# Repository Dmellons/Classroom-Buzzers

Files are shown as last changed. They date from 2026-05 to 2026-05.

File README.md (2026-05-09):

# ESP32 Quiz Buzzer System

A professional quiz buzzer system built with ESP32-C6 microcontrollers, featuring wireless button communication via ESP-NOW, web-based configuration, and real-time OLED display feedback.




## 🎯 Features

- **Up to 9 Teams**: Support for 1-9 wireless buzzer buttons
- **ESP-NOW Communication**: Ultra-low latency (<10ms) wireless protocol
- **Web Configuration Interface**: Easy setup via WiFi hotspot
- **OLED Display**: Real-time game status, team names, and winner display
- **SD Card Logging**: Permanent record of all buzzer events with timestamps
- **Auto-Load Configuration**: Team names and settings automatically restored on power-up
- **Built-in LED Feedback**: Arcade buttons with integrated illumination
- **Battery Powered Buttons**: Rechargeable 18650 Li-ion batteries with TP4056 charging
- **Persistent Configuration**: Team names and settings saved to SD card

## 📸 Demo

*[Add photos of your completed system here]*

## 🛠️ Hardware Requirements

### Base Station (1x)
- ESP32-C6-DevKitC-1 development board
- 128x64 OLED Display (I2C, SSD1306)
- MicroSD Card Reader Module (SPI)
- MicroSD Card (formatted FAT32)
- USB cable for power
- Jumper wires

### Button Units (1-9x, one per team)
- ESP32-C6-DevKitC-1 development board
- 60mm LED Arcade Button
- 18650 Li-ion Battery (3.7V, protected recommended)
- TP4056 Battery Charging Module
- MT3608 DC-DC Boost Converter (x2 per button)
- 10kΩ Resistor
- 1kΩ Resistor (for transistor base)
- 2N2222 or similar NPN transistor (for LED control)
- Toggle Switch (power switch)
- 18650 Battery Holder
- Jumper wires

### Optional
- WS2812B LED Strip (for visual effects on base station)
- Logic Level Converter (3.3V to 5V, if using LED strip)
- External 5V power supply (for LED strip)

## 📁 Repository Structure

```
Classroom Buzzers/
├── base-station/              # Base station code
│   ├── base-station.ino       # Main base station firmware
│   ├── base-secret.h          # WiFi credentials (create from template)
│   └── README.md              # Base station setup guide
├── button/                    # Button unit code
│   ├── button.ino             # Main button firmware
│   ├── button-secret.h        # Base station MAC (create from template)
│   └── README.md              # Button unit setup guide
├── debug/                     # Debug utilities
│   └── debug.ino              # Hardware diagnostic tool
├── tests/                     # Test utilities
│   └── blink-test/
│       └── blink-test.ino     # Basic LED blink test
├── components-list.md         # Complete hardware BOM and wiring
├── button-wiring-guide.md     # Detailed button wiring guide
├── breadboard-button-guide.md # Simplified breadboard setup
├── speaker-wiring-guide.md    # Audio system wiring
├── CLAUDE.md                  # Development guide for AI assistance
├── LICENSE                    # MIT License
└── README.md                  # This file
```

## Secret Configuration Files

These files contain sensitive information (WiFi credentials and MAC addresses) and should not be committed to version control.

You will need to create two secret files - one for the base station and one for each button unit:

### base-station/base-secret.h
```cpp
#define WIFI_SSID "QuizBuzzer-Setup"
#define WIFI_PASSWORD "buzzer123"
```

### button/button-secret.h
```cpp
#define BASE_STATION_MAC {0x00, 0x00, 0x00, 0x00, 0x00, 0x00}
```

## 🚀 Quick Start

### 1. Flash the Base Station
1. Open `base-station/base-station.ino` in Arduino IDE
2. Select **Board: "ESP32C6 Dev Module"**
3. Install required libraries (see base-station/README.md)
4. Upload the code
5. Note the MAC address from Serial Monitor

### 2. Flash the Buttons
1. Open `button/button.ino` in Arduino IDE
2. Update `baseStationMAC` with your base station's MAC address
3. Upload to each button ESP32
4. Note each button's MAC address from Serial Monitor

### 3. Configure the System
1. Power on the base station
2. Connect to WiFi network: **QuizBuzzer-Setup** (password: `buzzer123`)
3. Navigate to **192.168.4.1** in your browser
4. Enter team names and button MAC addresses
5. Click "Save Configuration"

### 4. Start Playing!
1. Click "START GAME" on the web interface
2. Press any button to test
3. The first buzzer lights up and displays on the OLED
4. Click "RESET ROUND" to play again

## 📚 Documentation

### Setup Guides
- **[Base Station Setup](base-station/README.md)** - Detailed wiring, code setup, and troubleshooting
- **[Button Setup](button/README.md)** - Button assembly, battery management, and configuration

### Hardware Documentation
- **[Components List](components-list.md)** - Complete hardware BOM and pin assignments
- **[Button Wiring Guide](button-wiring-guide.md)** - Detailed wiring for battery-powered buttons
- **[Breadboard Guide](breadboard-button-guide.md)** - Simplified USB-powered setup for testing
- **[Speaker Wiring Guide](speaker-wiring-guide.md)** - Audio system wiring
- **[Hardware Reference](docs/HARDWARE_REFERENCE.md)** - Complete hardware specifications

### Technical Documentation
- **[Software Architecture](docs/SOFTWARE_ARCHITECTURE.md)** - Code structure and functions
- **[ESP-NOW Protocol](docs/ESP_NOW_PROTOCOL.md)** - Communication protocol details
- **[LLM Context](docs/LLM_CONTEXT.md)** - Complete system overview for AI assistants

### 3D Printing
- **[Enclosure Guide](enclosure/README.md)** - 3D printable housing designs
- **[How to Generate STL](enclosure/HOW_TO_GENERATE_STL.md)** - Convert OpenSCAD to STL files

### Development
- **[CLAUDE.md](CLAUDE.md)** - AI development guide
- **[CHANGELOG.md](CHANGELOG.md)** - Development history

## 🔧 Troubleshooting

### Display Not Working
- Check I2C wiring (SDA=GPIO6, SCL=GPIO7 for ESP32-C6)
- Verify display is powered by 3.3V (NOT 5V)
- Run I2C scanner to confirm address (usually 0x3C)

### Button Not Registering
- Verify button MAC address is correctly entered in base station config
- Check that game has been started via web interface
- Ensure button battery is charged

### ESP-NOW Connection Issues
- Make sure both base station and buttons use the same WiFi channel
- Check that base station MAC is correctly set in button code
- Verify all grounds are connected in button circuit

## 📝 License

This project is licensed under the MIT License - see the [LICENSE](LICENSE) file for details.

## 🙏 Acknowledgments

- Built on the ESP32
- Uses Adafruit GFX and SSD1306 libraries for display
- Inspired by classic quiz show buzzer systems

---

**Made with ❤️ for my wife, Mrs. J**

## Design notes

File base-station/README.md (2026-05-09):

# Base Station Setup Guide

The base station is the central hub of the quiz buzzer system. It receives button presses via ESP-NOW, displays the winner on an OLED screen, logs all events to an SD card, and provides a web interface for configuration.

## 📋 Hardware Components

| Component | Quantity | Notes |
|---|---|---|
| ESP32-C6-DevKitC-1 | 1 | Main microcontroller |
| 128x64 OLED Display (I2C) | 1 | SSD1306 chip, 0x3C address |
| MicroSD Card Module | 1 | SPI interface |
| MicroSD Card | 1 | Any size, formatted FAT32 |
| Momentary Push Buttons | 2 | For Start/Stop and Reset controls |
| USB Cable | 1 | For power (5V) |
| Jumper Wires | Various | For connections |

### Optional Components
| Component | Quantity | Notes |
|---|---|---|
| WS2812B LED Strip | 1 | For visual effects |
| Logic Level Converter | 1 | 3.3V to 5V, for LED strip |
| 330Ω Resistor | 1 | For LED data line |
| External 5V Power Supply | 1 | For LED strip |

## 🔌 Wiring Diagram

### OLED Display (I2C)
```
ESP32-C6 Pin    →    OLED Pin
GPIO6 (SDA)     →    SDA
GPIO7 (SCL)     →    SCL
3.3V            →    VCC
GND             →    GND
```

⚠️ **CRITICAL**: Use 3.3V, NOT 5V! Most OLED displays are damaged by 5V.

### SD Card Reader (SPI)
```
ESP32-C6 Pin    →    SD Card Pin
GPIO23 (MOSI)   →    MOSI/DI
GPIO19 (MISO)   →    MISO/DO
GPIO18 (SCK)    →    SCK/CLK
GPIO5 (CS)      →    CS
3.3V            →    VCC
GND             →    GND
```

### Physical Control Buttons
```
ESP32-C6 Pin    →    Button Connection
GPIO10          →    Start/Stop Button (one side)
GPIO1           →    Reset Button (one side)
GND             →    Both buttons (other side)
```

**Button Wiring Details:**
- Both buttons use internal pull-up resistors (no external resistor needed)
- Wire one side of each button to its respective GPIO pin
- Wire the other side of both buttons to any ESP32 GND pin
- Buttons are active LOW (pressed = LOW, released = HIGH)
- Built-in debouncing with 250ms delay

**Button Functions:**
- **Start/Stop (GPIO10)**: Toggles between game active/stopped states
- **Reset (GPIO1)**: Resets the current round (clears winner)

⚠️ **Note**: Avoid GPIO0 (boot mode), GPIO3 (JTAG), and GPIO9 (boot strapping) for buttons as they have special functions on ESP32 boards.

### WS2812B LED Strip (Optional)
```
Component                      →    Connection
External 5V Supply (+)         →    LED Strip 5V
External 5V Supply (-)         →    LED Strip GND
ESP32 GPIO4                    →    Logic Level Converter (Low Side Input)
Logic Level Converter Output   →    330Ω Resistor → LED Strip Data In
ESP32 GND                      →    External Supply GND (COMMON GROUND!)
```

### Power
```
USB 5V → ESP32 USB-C Port
```

## 📚 Required Arduino Libraries

### base-station/base-secret.h
```cpp
#define WIFI_SSID "QuizBuzzer-Setup"
#define WIFI_PASSWORD "buzzer123"
```

Install these libraries via Arduino IDE Library Manager:

1. **ESP32 Board Support**
   - Go to File → Preferences
   - Add to Additional Board Manager URLs:
     ```
     https://espressif.github.io/arduino-esp32/package_esp32_index.json
     ```
   - Tools → Board → Board Manager → Search "esp32" → Install

2. **Adafruit GFX Library** (by Adafruit)
3. **Adafruit SSD1306** (by Adafruit)
4. **Adafruit BusIO** (dependency, should auto-install)

Built-in libraries (no installation needed):
- WiFi
- WebServer
- esp_now
- FS
- SD
- SPI
- Wire

## ⚙️ Board Settings

In Arduino IDE, select:
- **Board**: "ESP32C6 Dev Module"
- **Upload Speed**: 921600
- **Flash Size**: "4MB (32Mb)"
- **Partition Scheme**: "Default 4MB with spiffs"
- **Port**: Select your USB port

## 🚀 Installation Steps

### 1. Flash the Base Station Code

1. Open `base-station.ino` in Arduino IDE
2. Select the correct board settings (above)
3. Click **Upload**
4. Open Serial Monitor (115200 baud)
5. **IMPORTANT**: Copy and save the MAC address shown (format: `XX:XX:XX:XX:XX:XX`)

Example output:
```
Base Station MAC Address: AA:BB:CC:DD:EE:FF
```

### 2. Prepare the SD Card

1. Format a microSD card as **FAT32**
2. Insert into the SD card module
3. The system will automatically create these files:
   - `config.txt` - Team names and button MAC addresses
   - `buzzer_log.txt` - Event log with timestamps

### 3. Initial Configuration

1. Power on the base station
2. The OLED should display:
   ```
   Quiz Buzzer System

   WiFi: QuizBuzzer-Setup
   IP: 192.168.4.1

   Teams (9):
   1. Team 1
   2. Team 2
   3. Team 3
   ...
   ```

3. Connect to WiFi:
   - **SSID**: QuizBuzzer-Setup
   - **Password**: buzzer123

4. Open browser and navigate to: **http://192.168.4.1**

5. Configure teams:
   - Set number of teams (1-9)
   - Enter team names
   - Enter each button's MAC address (you'll get these when you flash the buttons)
   - Click "Save Configuration"

6. **Configuration saved!** On next power-up, the display will show:
   ```
   Quiz Buzzer System
   [Config Loaded]

   WiFi: QuizBuzzer-Setup
   IP: 192.168.4.1

   Teams (9):
   1. Team Alpha
   2. Team Beta
   3. Team Gamma
   4. Team Delta
   ...
   ```

## 🎮 Operating the System

You can control the base station using **either** the web interface or the physical buttons.

### Web Interface Controls

The web interface at `192.168.4.1` provides these controls:

- **START GAME** - Activates buzzer system, OLED shows "READY!"
- **RESET ROUND** - Clears current winner, ready for next question
- **STOP GAME** - Deactivates buzzer system
- **Mute Toggle** - Each team has individual mute control to silence their button's audio feedback
- **Save Configuration** - Saves team names, MAC addresses, and mute settings to SD card

### Physical Button Controls

Two physical buttons are wired to the base station for quick game control:

- **Start/Stop Button (GPIO10)** - Toggles game between active and stopped states
  - Press when stopped → Starts the game
  - Press when active → Stops the game
- **Reset Button (GPIO1)** - Resets the current round
  - Clears the winner
  - Resets response timer
  - Only sends updates when game is active

Both control methods work identically and can be used interchangeably during gameplay.

### Game Flow

1. **Start the game** (web or physical button)
2. OLED displays "READY!" in large text
3. First button press:
   - Button LED stays on
   - OLED displays "WINNER: [Team Name]"
   - Other buttons are locked out (LEDs off)
4. **Reset round** to clear and play again (web or physical button)
5. **Stop game** when finished (web or physical button)

## 📊 Data Logging

### Buzzer Log Format
File: `buzzer_log.txt`
```
12543,Team Alpha
15892,Team Beta
23401,Team Alpha
```
Format: `timestamp_ms,team_name`

### Configuration File Format
File: `config.txt`

The system automatically saves and loads your configuration on every boot. When you save settings via the web interface, they're written to `config.txt`:

```
9
Team Alpha
A4,B2,31,F0,12,34
1
0
Team Beta
A4,B2,31,F0,12,35
1
0
Team Gamma
A4,B2,31,F0,12,36
1
0
...
```

Format per team:
- Line 1: Team name
- Line 2: MAC address (comma-separated hex bytes)
- Line 3: Configuration status (1 = configured, 0 = not configured)
- Line 4: Mute status (1 = muted, 0 = not muted)

**Auto-Load Feature:**
- Configuration is automatically loaded on every power-up
- Team names and MAC addresses are restored
- Display shows `[Config Loaded]` when successful
- If no SD card or config file exists, defaults are used (Team 1, Team 2, etc.)

**Benefits:**
- No need to reconfigure after power cycles
- Portable - move system between locations without losing setup
- Backup your config by copying `config.txt` from the SD card

## 🔧 Troubleshooting

### OLED Display Issues

**Symptom**: Blank display
- **Check I2C wiring**: Verify SDA→GPIO6, SCL→GPIO7
- **Check voltage**: Must be 3.3V, not 5V
- **Run I2C Scanner**: Use the scanner code from main README
- **Try different address**: Change `0x3C` to `0x3D` in code (line 296)

**Symptom**: Display shows garbage/random pixels
- **Check power**: Ensure stable 3.3V supply
- **Check wiring**: Loose connections cause corruption

### SD Card Issues

**Symptom**: "SD Card failed" in Serial Monitor
- **Format**: Must be FAT32 (not exFAT or NTFS)
- **Check wiring**: Verify SPI connections
- **Try different card**: Some cards are incompatible
- **Check CS pin**: Should be GPIO5

**Symptom**: Configuration doesn't persist
- SD card may not be inserted or formatted correctly
- System will work without SD card, but won't save settings
- Check Serial Monitor for "Configuration file loaded successfully" message
- Verify `config.txt` exists on SD card after saving

**Symptom**: Display shows default team names instead of saved names
- Config file may be corrupted
- Try removing and reinserting SD card
- Check Serial Monitor for load errors
- Manually verify `config.txt` format on SD card
- Re-save configuration via web interface

### WiFi/Web Interface Issues

**Symptom**: Can't connect to QuizBuzzer-Setup
- **Restart ESP32**: Unplug and replug USB
- **Check Serial Monitor**: Verify AP started successfully
- **Try different device**: Some phones/laptops have issues with ESP32 APs

**Symptom**: Can't access 192.168.4.1
- **Verify WiFi connection**: Must be connected to QuizBuzzer-Setup
- **Try http://192.168.4.1**: Don't use https://
- **Clear browser cache**: Sometimes helps

### Button Communication Issues

**Symptom**: Buttons not registering
- **Check MAC addresses**: Must match exactly in config
- **Start the game**: Buttons won't work unless game is started
- **Check Serial Monitor**: Look for ESP-NOW errors
- **Restart both devices**: Sometimes ESP-NOW needs a reset

## 🔐 Security Note

The default WiFi password is `buzzer123`. For public events, consider changing it in the code (line 18):

```cpp
const char* ap_password = "your_secure_password_here";
```

## 📝 Customization

### Change Number of Teams
Default is now 9 teams. To change this, edit `MAX_TEAMS` in the code (base-station.ino:54):
```cpp
#define MAX_TEAMS 9  // Change to any value 1-9
```
You don't need to use all 9 slots - simply configure only the teams you need via the web interface.

### Change WiFi SSID
Edit line 17:
```cpp
const char* ap_ssid = "YourCustomName";
```

### Adjust OLED Brightness
The SSD1306 has built-in brightness control. Add this after display initialization:
```cpp
display.ssd1306_command(SSD1306_SETCONTRAST);
display.ssd1306_command(128); // 0-255, default is 207
```

## 💾 Code Structure

Key functions:
- `setup()` - Initializes hardware, WiFi, and loads saved configuration
- `loop()` - Handles web server
- `onDataRecv()` - ESP-NOW callback for button presses
- `updateDisplay()` - Updates OLED with current state and team names
- `handleRoot()` - Generates web interface HTML
- `saveConfig()` - Writes configuration to SD card
- `loadConfig()` - Automatically loads configuration on boot

## 🆘 Getting Help

If you encounter issues:
1. Check the Serial Monitor output for error messages
2. Verify all wiring matches the diagrams exactly
3. Test components individually (I2C scanner, SD card test, etc.)
4. Open an issue on GitHub with Serial Monitor output

---

**Next Step**: Set up your button units! See [button/README.md](../button/README.md)

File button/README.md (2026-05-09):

# Button Unit Setup Guide

Each button unit is a self-contained wireless buzzer powered by a LiPo battery. It communicates with the base station using ESP-NOW and provides:
- **OLED Display** showing team name, battery level, and game status
- **Audio Feedback** with buzzer sounds, victory tunes, and lockout tones
- **Visual Feedback** through built-in status LED and optional arcade button LED
- **Battery Monitoring** with real-time voltage and percentage display
- **Team Name Sync** via automatic heartbeat system

## 📋 Hardware Components (Per Button)

### Required Components

| Component | Quantity | Specifications |
|---|---|---|
| ESP32-C6-DevKitC-1 | 1 | Main microcontroller |
| 0.91" OLED Display | 1 | 128x32 I2C SSD1306 |
| 3W Speaker | 1 | 3W 8Ω speaker for audio feedback |
| 60mm LED Arcade Button | 1 | Large arcade button with microswitch |
| 503035 LiPo Battery | 1 | 3.7V 500mAh (or 18650 for longer runtime) |
| TP4056 Charging Module | 1 | With protection circuit |
| MT3608 Boost Converter | 1 | For ESP32 (3.7V→5V) |
| 10kΩ Resistor | 1 | For button pull-down |
| 1kΩ Resistor | 1 | For power LED |
| 47kΩ Resistor | 2 | For battery voltage divider |
| Power Indicator LED | 1 | 3mm or 5mm, any color |
| Toggle Switch | 1 | SPST, for main power |
| Jumper Wires | Various | 22-24 AWG recommended |

### Optional Components (for Arcade Button LED Illumination)

| Component | Quantity | Specifications |
|---|---|---|
| MT3608 Boost Converter | 1 | For LED (3.7V→12V) |
| 2N2222 NPN Transistor | 1 | Or any similar NPN transistor |
| 1kΩ Resistor | 1 | For transistor base |
| 330Ω Resistor | 1 | LED current limiting |

## 🔌 Wiring Diagram

### Complete Pin Assignments

| Function | ESP32-C6 Pin | Notes |
|---|---|---|
| OLED SDA | GPIO6 | I2C data |
| OLED SCL | GPIO7 | I2C clock |
| Button Input | GPIO15 | With 10kΩ pull-down |
| Status LED | GPIO2 | Built-in LED |
| Speaker | GPIO8 | PWM audio output |
| Battery Monitor | GPIO1 | ADC voltage sensing |
| LED Control | GPIO4 | Optional arcade button LED |
| Power (5V) | VIN | From boost converter |
| Ground | GND | Common ground |

### Power System
```
503035 LiPo Battery (+) → TP4056 BAT+
503035 LiPo Battery (-) → TP4056 BAT-

TP4056 OUT+ → Toggle Switch → Boost Converter IN+
TP4056 OUT- → Boost Converter IN-

Boost Converter (5V for ESP32):
  OUT+ (adjusted to 5V) → ESP32 VIN
  OUT- (GND) → ESP32 GND

Power Indicator LED:
  TP4056 OUT+ (after switch) → 1kΩ Resistor → Power LED (+)
  Power LED (-) → Common Ground

Battery Voltage Monitor:
  TP4056 OUT+ → 47kΩ → ESP32 GPIO1 → 47kΩ → GND
  (Voltage divider for battery level sensing)
```

⚠️ **CRITICAL**: All grounds must be connected together!
⚠️ **NOTE**: Use GPIO1 for battery monitoring, NOT GPIO0 (boot strapping pin)

### OLED Display (I2C)
```
ESP32 GPIO6 (SDA) → OLED SDA
ESP32 GPIO7 (SCL) → OLED SCL
ESP32 3.3V → OLED VCC
ESP32 GND → OLED GND
```

⚠️ **CRITICAL**: Use 3.3V for OLED, NOT 5V!

### Speaker (3W 8Ω Audio)
```
ESP32 GPIO8 → Speaker + (Positive)
ESP32 GND → Speaker - (Negative)
```

No amplifier needed - ESP32 can drive 3W speaker directly via PWM.

### Button Input Circuit
```
Arcade Button:
  NO (Normally Open) → ESP32 3.3V
  COM (Common) → ESP32 GPIO15

10kΩ Pull-down Resistor:
  One end → ESP32 GPIO15
  Other end → ESP32 GND
```

The button uses internal pull-down configuration with external 10kΩ resistor for reliability.

### LED Control Circuit (Optional - for Arcade Button Illumination)
```
Boost Converter #2 (12V for LED):
  IN+ → TP4056 OUT+ (after switch)
  IN- → TP4056 OUT-
  OUT+ (adjusted to 12V) → 2N2222 Collector

ESP32 GPIO4 → 1kΩ Resistor → 2N2222 Base
2N2222 Emitter → 330Ω Resistor → Button LED (+)
Button LED (-) → GND
```

### Charging Port
```
USB 5V+ → TP4056 IN+
USB GND → TP4056 IN-
```

💡 **Tip**: Mount the TP4056 module so the micro-USB port is accessible from outside your enclosure for easy charging.

## ⚙️ Boost Converter Setup

**BEFORE connecting to ESP32 or LED, adjust the boost converter(s)!**

### Boost Converter (ESP32 Power) - REQUIRED
1. Connect input to a 3.7V source (or the battery)
2. Connect a multimeter to the output
3. Use a small screwdriver to adjust the potentiometer
4. Set output to exactly **5.0V**
5. Mark this converter "ESP32 - 5V"

### Boost Converter #2 (LED Power) - OPTIONAL
Only needed if you want to illuminate the arcade button LED:
1. Connect input to a 3.7V source
2. Connect a multimeter to the output
3. Adjust potentiometer to **12V** (or 5V if your button LED is 5V)
4. Mark this converter "LED - 12V"

⚠️ **Check your button LED voltage!** Some arcade buttons use 5V LEDs, others use 12V. Adjust accordingly.

## 📚 Required Arduino Libraries

Install these libraries via Arduino IDE Library Manager:

1. **ESP32 Board Support**
   - Go to File → Preferences
   - Add to Additional Board Manager URLs:
     ```
     https://espressif.github.io/arduino-esp32/package_esp32_index.json
     ```
   - Tools → Board → Board Manager → Search "esp32" → Install

2. **Adafruit GFX Library** (by Adafruit) - for OLED display
3. **Adafruit SSD1306** (by Adafruit) - for OLED display
4. **Adafruit BusIO** (dependency, should auto-install)

Built-in libraries (no installation needed):
- esp_now
- WiFi
- Wire (I2C for OLED)

## 🚀 Installation Steps

### 1. Get Base Station MAC Address

You need the base station's MAC address before programming buttons.

From base station Serial Monitor, copy the MAC address, which looks like:
```
Base Station MAC Address: AA:BB:CC:DD:EE:FF
```

### 2. Program the Button

1. Open `button.ino` in Arduino IDE
2. **CRITICAL STEP**: Update line 16 with your base station's MAC address:
   ```cpp
   uint8_t baseStationMAC[] = {0xAA, 0xBB, 0xCC, 0xDD, 0xEE, 0xFF};
   ```
   
   Example conversion:
   - MAC: `A4:B2:31:F0:12:34`
   - Code: `{0xA4, 0xB2, 0x31, 0xF0, 0x12, 0x34}`

3. Select board settings:
   - **Board**: "ESP32C6 Dev Module"
   - **Upload Speed**: 921600
   
4. Click **Upload**

5. Open Serial Monitor (115200 baud)

6. **IMPORTANT**: Copy and save this button's MAC address:
   ```
   Button MAC Address: BB:CC:DD:EE:FF:11
   ```

7. Repeat for each button, saving each unique MAC address

### 3. Register Buttons with Base Station

1. Connect to base station WiFi: `QuizBuzzer-Setup`
2. Navigate to `http://192.168.4.1`
3. Enter each button's MAC address in the corresponding team slot
4. Click "Save Configuration"

## 🔋 Battery Management

### Charging
1. Plug micro-USB cable into TP4056 module
2. Red LED = Charging
3. Blue/Green LED = Fully charged
4. Charging time: ~1 hour for 503035 500mAh battery

### Battery Life
Expected runtime (approximate with 503035 500mAh battery):
- **Idle/waiting**: 4-6 hours
- **Active use** (frequent presses): 2-3 hours

💡 **Tip**: Implement deep sleep (see customization section) for much longer battery life. The compact 503035 battery is ideal for portable use while keeping the unit small and lightweight.

### Safety
- ✅ Use quality LiPo batteries from reputable sources
- ✅ TP4056 provides overcharge/overdischarge protection
- ❌ Don't leave charging unattended for extended periods
- ❌ Don't use damaged or swollen batteries
- ❌ LiPo batteries are sensitive - handle with care

## 🎮 Button Operation

### Power On
1. Flip toggle switch to ON
2. Built-in LED blinks twice (indicates ready)
3. Startup melody plays on speaker
4. OLED display shows connection status

### Display States

#### Connected (Team Name Received)
```
┌──────────────────┐
│ Team Alpha   85% │  ← Battery indicator
│                  │
│  Ready to play!  │
└──────────────────┘
```

#### Disconnected (Not Configured)
```
┌──────────────────┐
│ A4:B2:31:F0  72% │  ← MAC address + battery
│ HB:OK M:5        │  ← Heartbeat status
│ Btn:3 Sent:8     │  ← Debug counters
└──────────────────┘
```

#### Game Ready
```
┌──────────────────┐
│ Team Alpha   85% │
│                  │
│     READY!       │  ← Large text
│   Press now!     │
└──────────────────┘
```

#### Winner
```
┌──────────────────┐
│ Team Alpha   85% │
│                  │
│    WINNER!       │  ← Large text
│  You got it!     │
└──────────────────┘
```

### Audio Feedback

The button plays different sounds for each state:
- **Startup**: Ascending melody (C-E-G-C)
- **Game Ready**: Single beep (600Hz, 200ms)
- **Button Press**: Descending buzz (800-600-400Hz)
- **Winner**: Victory fanfare (800Hz → 1000Hz)
- **Locked Out**: Sad descending tone (400-300-200Hz)
- **Invalid Press**: Low error tone (200Hz)

Audio can be individually muted per team from the base station web interface.

### LED Status Patterns

Built-in status LED (GPIO2):
- **Waiting**: Slow pulse every 3 seconds
- **Ready**: Fast blink (500ms on/off)
- **Winner**: Solid on
- **Locked Out**: Off

### Battery Monitoring

- Battery percentage shown in top-right of display
- Updates every 30 seconds
- Voltage range: 3.0V (0%) to 4.2V (100%)
- LiPo discharge curve calculated automatically

### Heartbeat System

- Button sends heartbeat every 10 seconds
- Base station responds with team name and game status
- Automatic team name synchronization
- Connection status shown on OLED

### Power Off
Flip toggle switch to OFF when not in use to conserve battery.

## 🔧 Troubleshooting

### Button Not Registering

**Check MAC Address**
- Verify button MAC is correctly entered in base station config
- MAC addresses are case-insensitive but must match exactly
- Check OLED display - should show team name when configured

**Check Game State**
- Game must be started on base station
- OLED should show "READY!" when game is active
- Serial Monitor should show "Button pressed - sending buzz"

**Check ESP-NOW Connection**
- OLED shows heartbeat status (HB:OK or HB:X)
- Serial Monitor shows "Send Status: Success" or "Fail"
- If "Fail", check base station MAC address in button-secret.h

### OLED Display Issues

**Blank Display**
- Check I2C wiring: SDA→GPIO6, SCL→GPIO7
- Verify 3.3V power (NOT 5V - will damage display!)
- Try I2C scanner sketch to detect address
- Default address is 0x3C, some use 0x3D

**Garbled Display**
- Check loose connections
- Verify stable 3.3V power supply
- Ensure common ground with ESP32

**Shows MAC but No Team Name**
- Button not configured in base station yet
- Check base station web interface configuration
- Verify heartbeat communication (HB:OK on display)

### Speaker/Audio Issues

**No Sound**
- Check speaker wiring to GPIO8
- Verify speaker polarity (shouldn't matter for PWM)
- Test with different tone frequencies
- Check if team is muted in base station config

**Distorted Sound**
- Speaker may be 4Ω instead of 8Ω (still works)
- Check for loose connections
- PWM frequency may need adjustment

### Battery Issues

**Battery Percentage Shows 0% or Wrong Value**
- Check voltage divider: 47kΩ → GPIO1 → 47kΩ → GND
- Verify using GPIO1, NOT GPIO0 (boot strapping pin)
- Measure actual battery voltage with multimeter
- Should read ~1.85V at GPIO1 for 3.7V battery

**Won't Charge**
- Check TP4056 red LED comes on when USB plugged in
- Verify USB power source provides at least 500mA
- Check battery isn't over-discharged (should be >2.5V)

**Drains Quickly**
- Check for short circuits with multimeter
- Verify ESP32 isn't constantly transmitting (check Serial Monitor)
- OLED and speaker use power - normal runtime is 2-4 hours
- Consider implementing deep sleep mode for longer life

**Won't Power On**
- Check toggle switch connections
- Verify boost converter is set to 5V
- Check battery voltage (should be 3.0-4.2V)
- Measure 5V at ESP32 VIN pin

### LED Issues (Optional Arcade Button LED)

**LED Not Working**
- Measure boost converter #2 output with multimeter (should be 12V)
- Check transistor connections and orientation
- Verify GPIO4 output with multimeter
- Check LED polarity: + to boost, - to transistor

**LED Too Dim/Bright**
- Adjust boost converter voltage
- Change 330Ω current limiting resistor

### Physical Button Issues

**Button Doesn't Click or Register**
- Arcade buttons need firm pressure
- Check button isn't jammed or damaged
- Verify GPIO15 connection
- Check 10kΩ pull-down resistor is connected
- Serial Monitor should show BtnPress counter incrementing

**False Triggers**
- Check 10kΩ pull-down resistor is connected properly
- Verify button NO/COM connections (not NC!)
- May need debouncing adjustment in code (currently 50ms)
- Check for electrical noise from other components

## 📝 Customization

### button/button-secret.h
```cpp
#define BASE_STATION_MAC {0x00, 0x00, 0x00, 0x00, 0x00, 0x00}
```

### Implement Deep Sleep for Battery Life

Add to end of `loop()`:
```cpp
// After 5 minutes of no button press, go to sleep
if (millis() - lastPressTime > 300000) {
  enterDeepSleep();
}
```

This will wake on button press and dramatically extend battery life.

### Adjust Debounce Delay

Change line 31:
```cpp
const unsigned long debounceDelay = 50; // Milliseconds
```
Increase if getting double-presses, decrease for faster response.

### Change Button Pin

To use a different GPIO pin for the button, update:
- Line 12: `#define BUTTON_PIN 15` → your pin number
- Line 90: `esp_sleep_enable_ext0_wakeup((gpio_num_t)BUTTON_PIN, HIGH);`

### Use Different LED Pin

To use a different GPIO for LED control:
- Line 13: `#define LED_PIN 2` → your pin number
- Line 14: `#define BOOST_EN_PIN 4` → your pin number

## 🔐 Security Considerations

ESP-NOW uses encryption by default in Arduino implementation. For additional security in public events, you can:
1. Enable ESP-NOW encryption (requires PMK/LMK keys)
2. Add a "pairing" button that only allows registration when pressed
3. Implement MAC address filtering

## 💾 Code Structure

Key functions:
- `setup()` - Initializes ESP-NOW, I2C, OLED, speaker, and button
- `loop()` - Checks for button press, sends heartbeats, updates display and battery
- `buttonISR()` - Hardware interrupt for instant button detection
- `onDataRecv()` - Receives status updates and team name from base station
- `onDataSent()` - Callback for ESP-NOW transmission status
- `sendBuzzer()` - Transmits button press via ESP-NOW
- `sendHeartbeat()` - Sends periodic heartbeat to base station
- `updateDisplay()` - Updates OLED with current state, team name, and battery
- `setStatusLED()` - Controls built-in status LED (GPIO2)
- `showStatePattern()` - Displays LED patterns based on game state
- `playTone()` - Generates PWM audio tones on speaker
- `playBuzzSound()` - Button press audio feedback
- `playWinnerSound()` - Victory fanfare
- `playLockoutSound()` - Lockout tone
- `playReadySound()` - Game ready beep
- `playStartupSound()` - Boot melody
- `readBatteryVoltage()` - Reads ADC from voltage divider (GPIO1)
- `calculateBatteryPercent()` - Converts voltage to percentage
- `updateBatteryLevel()` - Updates battery display
- `drawBatteryIcon()` - Draws battery indicator on OLED

## 📦 Enclosure Recommendations

Consider housing each button unit in:
- **3D printed case** - Custom design for perfect fit
- **Project box** - Hammond or similar, drill hole for button
- **Arcade button housing** - Purpose-built for arcade buttons

Mount considerations:
- Make TP4056 USB port accessible for charging
- Expose toggle switch for easy on/off
- Ensure button is securely mounted
- Consider strain relief for any external wiring

## 🧪 Testing Checklist

Before final assembly:
- [ ] Boost converter set to 5.0V (measure with multimeter)
- [ ] OLED display initializes and shows MAC address
- [ ] Speaker plays startup melody on power-on
- [ ] Button press registers in Serial Monitor (BtnPress counter increments)
- [ ] Built-in status LED blinks on power-up
- [ ] Battery percentage displays correctly on OLED
- [ ] ESP-NOW communication successful (HB:OK on display)
- [ ] Team name appears on OLED after base station configuration
- [ ] All game state sounds play correctly (ready, buzz, winner, lockout)
- [ ] Battery charges properly (TP4056 LED indicators: red=charging, blue/green=full)
- [ ] Toggle switch cuts power completely
- [ ] No short circuits (check all power rails with multimeter)
- [ ] Optional: Arcade button LED lights up (if using LED control circuit)

## 🆘 Getting Help

If you encounter issues:
1. Check Serial Monitor for error messages
2. Test each component individually
3. Verify all connections match wiring diagram
4. Measure voltages with multimeter
5. Open a GitHub issue with:
   - Serial Monitor output
   - Photos of your wiring
   - Description of the problem

---

**Next Step**: Test your complete system! See the [main README](../README.md) for game operation.

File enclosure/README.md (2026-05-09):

# 3D Printable Enclosure Guide

This directory contains parametric OpenSCAD designs for the button unit housing.

## Files

- `button-housing.scad` - Parametric OpenSCAD source file

## Generating STL Files

### Option 1: Using OpenSCAD (Recommended)

1. **Download and install OpenSCAD**: https://openscad.org/downloads.html

2. **Open the file**: `button-housing.scad`

3. **Render and export**:
   - Press **F6** to render (this may take a minute)
   - File → Export → Export as STL
   - Save as `button-housing-bottom.stl`

4. **Export top half**:
   - Edit the file, uncomment the top half render option:
     ```
     // Option 3: Top half only (for printing - flip in slicer)
     translate([0, 0, lid_height]) rotate([180, 0, 0]) top_half();
     ```
   - Comment out the bottom half line
   - Press **F6** to render
   - Export as `button-housing-top.stl`

### Option 2: Online Converter

If you don't want to install OpenSCAD:
1. Go to https://www.viewstl.com/ or similar
2. Some online services can convert SCAD to STL
3. Note: Complex parametric designs may not work with all converters

### Option 3: Request Pre-Generated STL

The OpenSCAD file is parametric, meaning dimensions can be adjusted. If you want pre-generated STL files with default dimensions, you can:
1. Ask in the GitHub Issues for STL exports
2. Use a 3D printing service that accepts SCAD files

## ABS Print Settings

**Recommended settings for ABS:**

| Setting | Value |
|---|---|
| Nozzle Temperature | 230-250°C |
| Bed Temperature | 90-110°C |
| Layer Height | 0.2mm |
| Infill | 20-30% |
| Walls/Perimeters | 3-4 |
| Top/Bottom Layers | 4-5 |
| Supports | Not needed for bottom, may need for top |

**Important ABS Tips:**
- Use an enclosed printer if possible (prevents warping)
- Use a heated bed with adhesion (glue stick, ABS slurry, or PEI sheet)
- Allow parts to cool slowly (don't open enclosure immediately)
- Consider printing with a brim for better bed adhesion

## Design Details

### Button Unit Dimensions
- **Internal**: 80mm x 100mm x 45mm
- **Wall Thickness**: 2.5mm
- **Corner Radius**: 5mm
- **Lid Overlap**: 2mm
- **Lid Tolerance**: 0.4mm (increased for easier assembly)

### Button Unit Cutouts (Verified Dimensions)
- **Top**: 28mm hole for 60mm arcade button
- **Front**: OLED window (23mm x 12mm) for 0.91" 128x32 display
- **Right Side**: Speaker grill (40mm diameter, 3mm holes)
- **Back**: USB-C port (10mm x 4.5mm, widened for easier cable insertion)
- **Left Side**: Toggle switch hole (6.2mm diameter)

### Base Station Dimensions
- **Internal**: 100mm x 80mm x 35mm
- **Wall Thickness**: 2.5mm
- **Corner Radius**: 5mm
- **Lid Tolerance**: 0.4mm (increased for easier assembly)

### Base Station Cutouts (Verified Dimensions)
- **Front**: OLED window (23mm x 13mm) for 0.96" 128x64 display
- **Top**: Two 12mm holes for control buttons
- **Back**: USB-C port (12mm x 8mm), SD card slot (30mm x 5mm)
- **Sides**: Ventilation slots for cooling

### Internal Features

**Button Unit:**
- Corner screw posts (M3 screw holes with chamfered entrances)
- OLED friction-fit pocket with 0.5mm tolerance
- ESP32 mounting rails (updated for 51.8mm length)
- TP4056 mounting rails near USB-C cutout
- Ventilation slots for boost converter heat dissipation
- Improved lid tolerance (0.4mm) for easier assembly

**Base Station:**
- Corner screw posts (M3 screw holes)
- OLED mounting ledge
- ESP32 mounting rails (updated for 51.8mm length)
- Ventilation slots on sides
- Improved OLED window sizing (23mm x 13mm)

## Verified Component Dimensions

All dimensions have been verified from manufacturer datasheets (December 2024):

### Button Unit Components
| Component | Actual Dimensions | Notes |
|---|---|---|
| ESP32-C6-DevKitC-1 | 25.4 × 51.8 × 10mm | Official Espressif specs |
| 0.91" OLED (128x32) | PCB: 38 × 12mm, Active: 22.4 × 5.6mm | SSD1306 I2C |
| 60mm Arcade Button | 28mm mounting hole | Standard size |
| 3W 8Ω Speaker | 40mm dia × 20mm height | For audio feedback |
| TP4056 Charger | 26 × 17mm | With protection circuit |
| MT3608 Boost | 37 × 17 × 14mm | Including potentiometer |
| 503035 LiPo Battery | 35 × 30 × 5mm | 500mAh capacity |
| Toggle Switch | 6mm mounting hole | SPST power switch |

### Base Station Components
| Component | Actual Dimensions | Notes |
|---|---|---|
| ESP32-C6-DevKitC-1 | 25.4 × 51.8 × 10mm | Official Espressif specs |
| 0.96" OLED (128x64) | PCB: 27 × 27mm, Active: 22 × 12mm | SSD1306 I2C |
| MicroSD Module | 20-28mm × 20-25mm | Varies by manufacturer |
| Momentary Buttons | 12mm mounting hole | Start/Stop and Reset |

## Customization

The OpenSCAD files are fully parametric. All component dimensions are defined at the top of each file and can be adjusted if you have different parts.

**Button Housing** (`button-housing.scad`):
```scad
// Verified dimensions (DO NOT change unless using different components)
esp32_length = 51.8;     // ESP32-C6 length
oled_window_w = 23;      // OLED window width
tp4056_length = 26;      // Charger module length
tp4056_width = 17;       // Charger module width
mt3608_length = 37;      // Boost converter length
mt3608_height = 14;      // Boost converter height
switch_hole_dia = 6.2;   // Toggle switch hole
usbc_width = 10;         // USB-C opening (widened)
usbc_height = 4.5;       // USB-C opening (widened)
```

**Base Station Housing** (`base-station-housing.scad`):
```scad
// Verified dimensions
esp32_length = 51.8;     // ESP32-C6 length
oled_window_w = 23;      // OLED window width
oled_window_h = 13;      // OLED window height
usbc_width = 12;         // USB-C opening
usbc_height = 8;         // USB-C opening
```

## Assembly

1. Print both halves (bottom upright, top flipped)
2. Install components in bottom half:
   - Mount ESP32 on rails
   - Secure TP4056 near USB port opening
   - Mount OLED behind window
   - Position speaker at grill
   - Wire battery and boost converter
3. Install toggle switch in side hole
4. Mount arcade button in top
5. Connect wires to button
6. Secure with M3 screws in corner posts

## Recent Updates (December 2024)

### Dimension Corrections
All component dimensions have been updated with verified measurements from manufacturer datasheets:
- **ESP32-C6**: Length corrected from 54mm to 51.8mm
- **Button OLED window**: Reduced from 24mm to 23mm width
- **Base OLED window**: Reduced from 30mm × 16mm to 23mm × 13mm
- **TP4056**: Corrected from 25mm × 19mm to 26mm × 17mm
- **MT3608**: Corrected from 36mm × 17mm × 10mm to 37mm × 17mm × 14mm
- **Toggle switch**: Changed from rectangular rocker (19mm × 13mm) to circular hole (6.2mm)

### Assembly Improvements
- **USB-C access**: Widened from 9mm × 3.5mm to 10mm × 4.5mm for easier cable insertion
- **Lid tolerance**: Increased from 0.3mm to 0.4mm for easier assembly
- **Speaker depth**: Added proper 20mm clearance specification
- **Ventilation**: Added heat dissipation slots for boost converter
- **OLED pocket**: Improved tolerances for easier installation

## Alternative: Simple Box Enclosure

If you prefer not to use this custom design, any project box around 100x80x50mm will work. You'll need to:
- Drill a 28mm hole for the arcade button
- Cut a window for the OLED (optional, can mount externally)
- Drill a 6mm hole for toggle switch (not rectangular rocker)
- Drill holes for USB charging and speaker sound

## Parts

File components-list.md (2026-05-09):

# Quiz Buzzer System - Complete Components List & Wiring

## System Overview

This is an ESP32-C6 based quiz buzzer system with:
- **Base Station**: Central hub with OLED display, SD logging, WiFi config, and physical controls
- **Button Units**: Battery-powered wireless buzzers with OLED display, speaker, and battery monitoring
- **Communication**: ESP-NOW protocol for ultra-low latency (<10ms)

### System Capabilities
- Support for 1-9 wireless button units
- Millisecond-precision response time measurement
- Automatic button discovery (no manual MAC entry required)
- Persistent configuration via SD card
- Individual team mute control
- Configurable countdown timer (1-5 seconds)
- Web interface for easy configuration
- Physical buttons for game control
- Battery monitoring with percentage display
- Audio feedback for all game states

---

## BASE STATION COMPONENTS

### Required Hardware

| Component | Quantity | Specifications | Notes |
|---|---|---|---|
| ESP32-C6-DevKitC-1 | 1 | Espressif ESP32-C6 development board | Main microcontroller |
| 128x64 OLED Display | 1 | I2C SSD1306, 0x3C address | Status display |
| MicroSD Card Module | 1 | SPI interface | For logging and config |
| MicroSD Card | 1 | Any size, FAT32 formatted | Data storage |
| Momentary Push Button | 2 | SPST, normally open | Start/Stop and Reset controls |
| USB Cable (USB-C) | 1 | For power (5V 1A minimum) | Powers entire system |
| Jumper Wires | Various | 22-24 AWG | Connections |

### Optional Hardware

| Component | Quantity | Specifications | Notes |
|---|---|---|---|
| WS2812B LED Strip | 1 | Addressable RGB LED strip | Visual effects |
| Logic Level Converter | 1 | 3.3V to 5V bi-directional | For LED strip data line |
| 330Ω Resistor | 1 | 1/4W | LED data line protection |
| External 5V Power Supply | 1 | 2A or higher | For LED strip |

### Base Station Pin Assignments (ESP32-C6)

| Function | GPIO Pin | Wire Color Suggestion | Notes |
|---|---|---|---|
| **OLED SDA** | GPIO6 | Blue | I2C data line |
| **OLED SCL** | GPIO7 | Yellow | I2C clock line |
| **SD MOSI** | GPIO23 | Orange | SPI data out |
| **SD MISO** | GPIO19 | Purple | SPI data in |
| **SD SCK** | GPIO18 | Green | SPI clock |
| **SD CS** | GPIO5 | White | SPI chip select |
| **Start/Stop Button** | GPIO10 | Brown | Uses internal pull-up |
| **Reset Button** | GPIO1 | Red | Uses internal pull-up |
| **LED Strip (Optional)** | GPIO4 | - | Via level converter |
| **Power (5V)** | USB-C | Red | Powers entire base |
| **Ground** | GND | Black | Common ground |
| **3.3V** | 3V3 | Red | For OLED and SD module |

### Base Station Wiring Diagram

```
ESP32-C6 BASE STATION CONNECTIONS
==================================

OLED Display (128x64 I2C):
  ESP32 GPIO6 (SDA) ──────────── OLED SDA
  ESP32 GPIO7 (SCL) ──────────── OLED SCL
  ESP32 3.3V ─────────────────── OLED VCC (⚠️ NOT 5V!)
  ESP32 GND ──────────────────── OLED GND

SD Card Reader (SPI):
  ESP32 GPIO23 (MOSI) ─────────── SD Card MOSI/DI
  ESP32 GPIO19 (MISO) ─────────── SD Card MISO/DO
  ESP32 GPIO18 (SCK) ──────────── SD Card SCK/CLK
  ESP32 GPIO5 (CS) ────────────── SD Card CS
  ESP32 3.3V ──────────────────── SD Card VCC
  ESP32 GND ───────────────────── SD Card GND

Physical Control Buttons:
  Button 1 (Start/Stop):
    ESP32 GPIO10 ────────────── One side of button
    ESP32 GND ───────────────── Other side of button
    (Uses internal pull-up resistor)

  Button 2 (Reset):
    ESP32 GPIO1 ─────────────── One side of button
    ESP32 GND ───────────────── Other side of button
    (Uses internal pull-up resistor)

WS2812B LED Strip (Optional):
  External 5V Supply (+) ──────── LED Strip 5V
  External 5V Supply (-) ──────── LED Strip GND
  ESP32 GPIO4 ──────────────────── Logic Level Converter (Low Side)
  Logic Level Converter (High) ──[330Ω]── LED Strip Data In
  ESP32 GND ───────────────────── External 5V Supply GND (COMMON GROUND!)

Power:
  USB-C 5V ──────────────────── ESP32 USB-C Port
```

### Critical Notes for Base Station
- ⚠️ **OLED MUST use 3.3V** - 5V will damage most OLED displays
- ⚠️ **SD Card MUST be FAT32** - exFAT and NTFS are not supported
- ⚠️ **Buttons use internal pull-ups** - no external resistors needed
- ⚠️ **Common ground required** - all GND pins must connect together
- 💡 GPIO10 and GPIO1 chosen to avoid boot strapping pins (GPIO0, GPIO9)

---

## BUTTON UNIT COMPONENTS (Per Button)

### Required Hardware

| Component | Quantity | Specifications | Estimated Cost |
|---|---|---|---|
| ESP32-C6-DevKitC-1 | 1 | Espressif ESP32-C6 development board | $15 |
| 0.91" OLED Display | 1 | 128x32 I2C SSD1306, 0x3C address | $8 |
| 3W Speaker | 1 | 3W 8Ω speaker for audio feedback | $6 |
| 60mm Arcade Button | 1 | Large dome button with microswitch | $12 |
| LiPo Battery | 1 | 503035 3.7V 500mAh (or 18650 for longer runtime) | $5-10 |
| TP4056 Module | 1 | Battery charging module with protection | $3 |
| MT3608 Boost Converter | 1 | DC-DC step-up (3.7V → 5V) for ESP32 | $2 |
| Toggle Switch | 1 | SPST, 3A rated, for main power | $2 |
| Power Indicator LED | 1 | 3mm or 5mm, any color | $0.50 |
| 10kΩ Resistor | 1 | 1/4W, button pull-down | $0.10 |
| 1kΩ Resistor | 1 | 1/4W, for power LED | $0.10 |
| 47kΩ Resistor | 2 | 1/4W, battery voltage divider | $0.20 |
| Jumper Wires | Various | 22-24 AWG stranded, various colors | $5 |
| Enclosure | 1 | Plastic project box or 3D printed | $10 |
| **Total (Required)** | | | **~$69** |

### Optional Hardware (Arcade Button LED Illumination)

| Component | Quantity | Specifications | Estimated Cost |
|---|---|---|---|
| MT3608 Boost Converter | 1 | DC-DC step-up (3.7V → 12V) for LED | $2 |
| 2N2222 NPN Transistor | 1 | Or any similar NPN switching transistor | $0.50 |
| 1kΩ Resistor | 1 | 1/4W, transistor base | $0.10 |
| 330Ω Resistor | 1 | 1/4W, LED current limiting | $0.10 |
| **Total (Optional LED)** | | | **~$3** |

### Button Unit Pin Assignments (ESP32-C6)

| Function | GPIO Pin | Wire Color Suggestion | Notes |
|---|---|---|---|
| **OLED SDA** | GPIO6 | Blue | I2C data line |
| **OLED SCL** | GPIO7 | Yellow | I2C clock line |
| **Button Input** | GPIO15 | Green | With 10kΩ pull-down |
| **Status LED** | GPIO2 | - | Built-in LED (onboard) |
| **Speaker** | GPIO8 | Purple | PWM audio output |
| **Battery Monitor** | GPIO1 | White | ADC voltage sensing |
| **LED Control** | GPIO4 | Orange | Optional arcade LED control |
| **Power (5V)** | VIN | Red | From boost converter |
| **Ground** | GND | Black | Common ground |
| **3.3V** | 3V3 | Red | For OLED |

### Button Unit Wiring Diagram

```
ESP32-C6 BUTTON UNIT CONNECTIONS
=================================

OLED Display (128x32 I2C):
  ESP32 GPIO6 (SDA) ──────────── OLED SDA
  ESP32 GPIO7 (SCL) ──────────── OLED SCL
  ESP32 3.3V ─────────────────── OLED VCC (⚠️ NOT 5V!)
  ESP32 GND ──────────────────── OLED GND

Speaker (3W 8Ω):
  ESP32 GPIO8 ────────────────── Speaker + (Positive)
  ESP32 GND ──────────────────── Speaker - (Negative)
  Note: Direct connection OK, ESP32 PWM can drive 3W speaker

Arcade Button Input:
  Button NO (Normally Open) ──── ESP32 3.3V
  Button COM (Common) ────────── ESP32 GPIO15
  10kΩ Resistor ──────────────── Between GPIO15 and GND (pull-down)

Battery Voltage Monitoring:
  TP4056 OUT+ ─[47kΩ]─┬─[47kΩ]─ GND
                       │
                  ESP32 GPIO1 (ADC)
  Note: Voltage divider reads half battery voltage

Status LED:
  ESP32 GPIO2 ────────────────── Built-in LED (onboard, no wiring needed)

Power System:
  503035 LiPo Battery (+) ────── TP4056 BAT+
  503035 LiPo Battery (-) ────── TP4056 BAT-

  TP4056 OUT+ ──┬── Toggle Switch ──┬── MT3608 Boost IN+
                │                    │
                └──[1kΩ]── Power LED (+)

  TP4056 OUT- ─────────────────────── MT3608 Boost IN-
  Power LED (-) ───────────────────── GND

  MT3608 Boost OUT+ (5V) ────────── ESP32 VIN
  MT3608 Boost OUT- (GND) ───────── ESP32 GND

Charging:
  USB 5V ──────────────────────── TP4056 IN+
  USB GND ─────────────────────── TP4056 IN-

Common Ground Network:
  ████ ALL THESE MUST BE CONNECTED ████
  - LiPo Battery (-)
  - TP4056 OUT- and GND
  - Boost Converter GND
  - ESP32 GND
  - OLED GND
  - Speaker (-)
  - Button circuit GND
  - Power LED (-)
  ████████████████████████████████████

Optional - Arcade Button LED Illumination:
  Second MT3608 Boost:
    IN+ ────────────────────────── TP4056 OUT+ (after switch)
    IN- ────────────────────────── TP4056 OUT-
    OUT+ (12V) ─────────────────── 2N2222 Collector

  LED Control Circuit:
    ESP32 GPIO4 ──[1kΩ]── 2N2222 Base
    2N2222 Emitter ──[330Ω]─── Button LED (+)
    Button LED (-) ──────────── GND
```

### Critical Notes for Button Units
- ⚠️ **OLED MUST use 3.3V** - 5V will damage the display
- ⚠️ **Battery monitoring uses GPIO1** - NOT GPIO0 (boot strapping pin causes issues)
- ⚠️ **Boost converter MUST be adjusted to 5.0V** before connecting to ESP32
- ⚠️ **Common ground critical** - all GND points must connect together
- ⚠️ **Button uses GPIO15** - confirmed working with external 10kΩ pull-down
- 💡 Speaker connects directly to GPIO8 - no amplifier needed for 3W 8Ω speaker
- 💡 GPIO1-7 are ADC-capable on ESP32-C6; GPIO18-23 are NOT ADC-capable
- 💡 Arcade button LED illumination is optional - core functionality works without it

---

## BOOST CONVERTER SETUP

### For Button Units (REQUIRED - ESP32 Power)
1. Connect boost converter input to 3.7V source (battery or bench supply)
2. Connect multimeter to output terminals
3. Adjust potentiometer slowly until output reads **exactly 5.0V**
4. Label converter "ESP32 - 5V"
5. Disconnect and install in circuit

### For Arcade Button LED (OPTIONAL - LED Illumination Only)
1. Connect boost converter input to 3.7V source
2. Connect multimeter to output terminals
3. Adjust potentiometer until output reads **12V** (or 5V if LED is 5V rated)
4. Label converter "LED - 12V"
5. Disconnect and install in circuit

**⚠️ WARNING**: Always set boost converter voltage BEFORE connecting to ESP32 or LED! Overvoltage can damage components.

---

## SYSTEM FEATURES

### Base Station Features
✅ 128x64 OLED display showing team names and game status
✅ SD card logging with auto-save configuration
✅ WiFi access point (192.168.4.1) for web configuration
✅ Physical buttons for game control (Start/Stop, Reset)
✅ ESP-NOW wireless communication (ultra-low latency)
✅ Individual team mute control via web interface
✅ Supports 1-9 teams (configurable)
✅ Persistent configuration (survives power cycles)

### Button Unit Features
✅ 128x32 OLED display with team name and battery level
✅ Audio feedback with 3W speaker (buzzer, victory, lockout sounds)
✅ Battery voltage monitoring and percentage display
✅ Automatic team name synchronization via heartbeat
✅ Visual status LED patterns for each game state
✅ Individual mute capability (controlled from base station)
✅ LiPo battery powered with USB charging
✅ 2-4 hour runtime (typical with 500mAh battery)
✅ Hardware interrupt button detection for instant response
✅ Built-in debouncing (50ms)

---

## ARDUINO LIBRARIES REQUIRED

### For All Devices (Base Station + Buttons)
1. **ESP32 Board Support**
   - File → Preferences → Additional Board Manager URLs:
   - `https://espressif.github.io/arduino-esp32/package_esp32_index.json`
   - Tools → Board → Board Manager → Search "esp32" → Install

2. **Adafruit GFX Library** (by Adafruit)
3. **Adafruit SSD1306** (by Adafruit)
4. **Adafruit BusIO** (dependency, usually auto-installs)

### Built-in Libraries (No Installation Needed)
- WiFi
- WebServer (base station only)
- esp_now
- Wire (I2C)
- FS (base station only)
- SD (base station only)
- SPI (base station only)

---

## BOARD SETTINGS (Arduino IDE)

**For Both Base Station and Button Units:**
- **Board**: "ESP32C6 Dev Module"
- **Upload Speed**: 921600
- **Flash Size**: "4MB (32Mb)"
- **Partition Scheme**: "Default 4MB with spiffs"
- **Port**: Select your USB port

---

## ASSEMBLY TIPS

### Base Station Assembly Order
1. Flash code to ESP32 first (note MAC address from Serial Monitor)
2. Test OLED display independently (I2C scanner if needed)
3. Test SD card module independently (format as FAT32)
4. Wire physical buttons to GPIO10 and GPIO1 (connect other side to GND)
5. Connect all components following wiring diagram
6. Verify all grounds are connected together
7. Power via USB-C cable or 5V wall adapter
8. Insert FAT32-formatted SD card
9. Access web interface at 192.168.4.1 to configure teams

### Button Unit Assembly Order
1. Flash code to ESP32 first (note MAC address from Serial Monitor)
2. **CRITICAL**: Adjust boost converter to 5.0V BEFORE connecting to ESP32
3. Test OLED display independently
4. Test speaker with startup sound
5. Wire battery voltage divider to GPIO1 (NOT GPIO0!)
6. Wire button to GPIO15 with 10kΩ pull-down to GND
7. Assemble power system (TP4056 → switch → boost → ESP32)
8. Connect all components following wiring diagram
9. Verify all grounds are connected together (critical!)
10. Test battery charging (TP4056 red LED = charging, blue/green = full)
11. Configure button MAC address in base station web interface
12. Test communication (OLED should show team name)

---

## TROUBLESHOOTING QUICK REFERENCE

### Base Station
- **OLED blank**: Check I2C wiring (GPIO6/7), verify 3.3V power
- **SD card fail**: Must be FAT32, check SPI wiring (GPIO5/18/19/23)
- **WiFi won't start**: Check Serial Monitor for errors, restart ESP32
- **Buttons not working**: Verify MAC addresses match in config exactly

### Button Units
- **OLED blank**: Check I2C wiring (GPIO6/7), verify 3.3V power (NOT 5V!)
- **No sound**: Check speaker wiring to GPIO8, verify team not muted
- **Wrong battery %**: Check voltage divider on GPIO1 (NOT GPIO0!)
- **Button not registering**: Check GPIO15 wiring, verify 10kΩ pull-down
- **No heartbeat (HB:X)**: Check base station MAC in button-secret.h
- **Won't power on**: Verify boost converter set to 5.0V, check battery voltage

---

## ESTIMATED TOTAL COST

### For Complete System (1 Base Station + 4 Button Units)

| Item | Cost |
|---|---|
| Base Station Hardware | ~$45 |
| Button Unit x4 (required components) | ~$276 ($69 each) |
| **Total System** | **~$321** |

**Per Additional Button**: ~$69

**Note**: Costs are estimates based on typical online prices. Bulk ordering can reduce costs significantly.

---

This wiring guide reflects the current implementation as of the latest code updates. All pin assignments, features, and wiring diagrams are accurate to the actual working system.

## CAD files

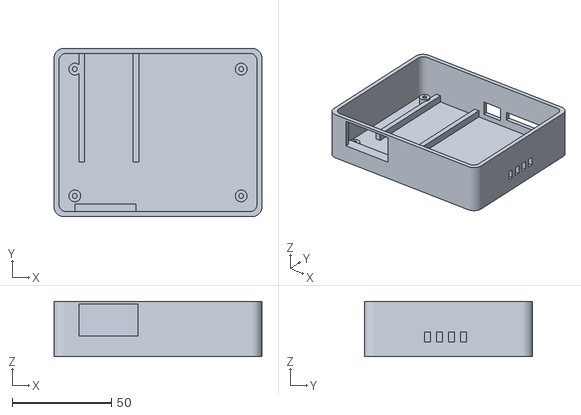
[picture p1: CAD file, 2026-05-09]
enclosure/base-station-housing.stl
105.0 x 85.0 x 28.0

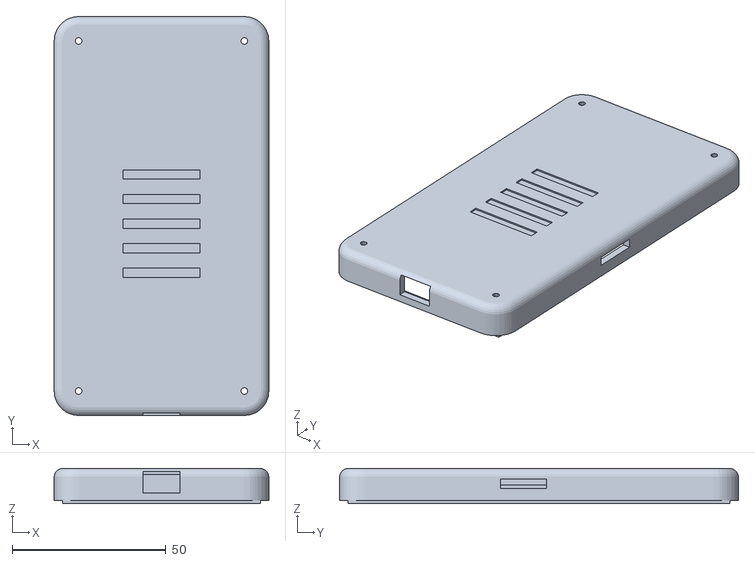
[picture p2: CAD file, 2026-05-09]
enclosure/base-station-handheld-back.stl
69.9 x 129.9 x 11.5

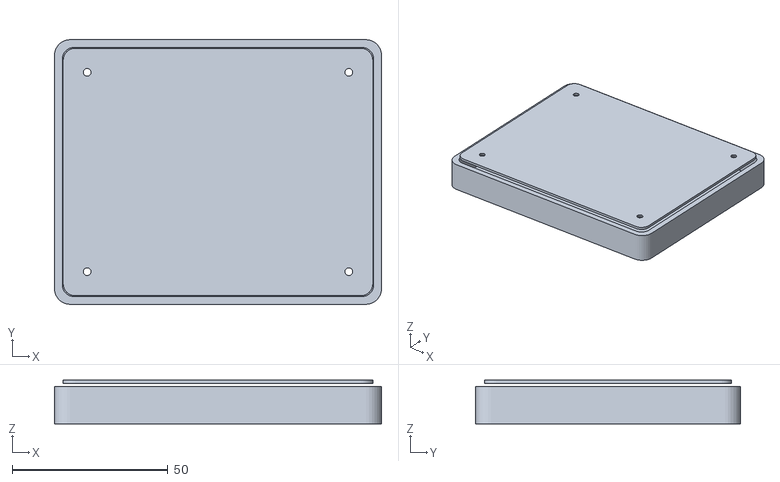
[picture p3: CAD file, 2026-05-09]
enclosure/base-station-top.stl
105.0 x 85.0 x 14.0

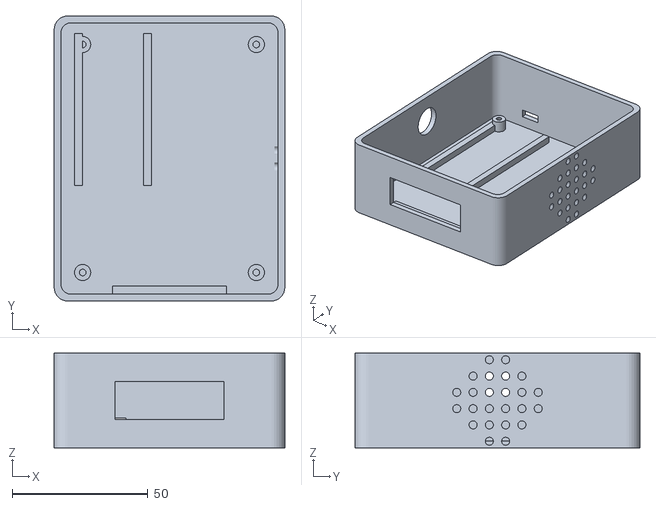
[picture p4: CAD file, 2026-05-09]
enclosure/button-housing bottom.stl
85.0 x 105.0 x 35.0

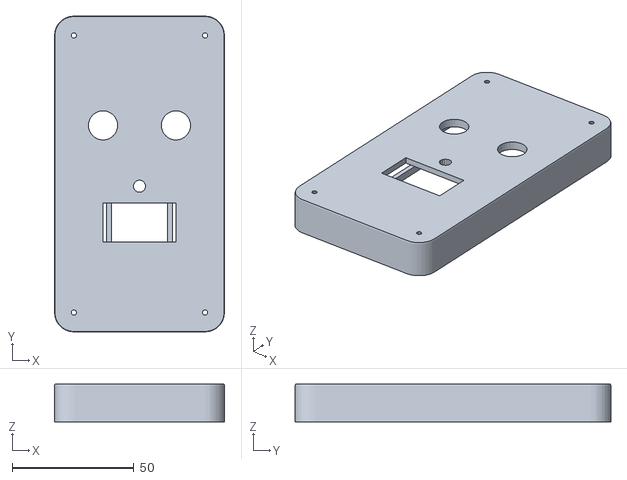
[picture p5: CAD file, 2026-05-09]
enclosure/base-station-handheld-front.stl
69.9 x 129.9 x 15.5

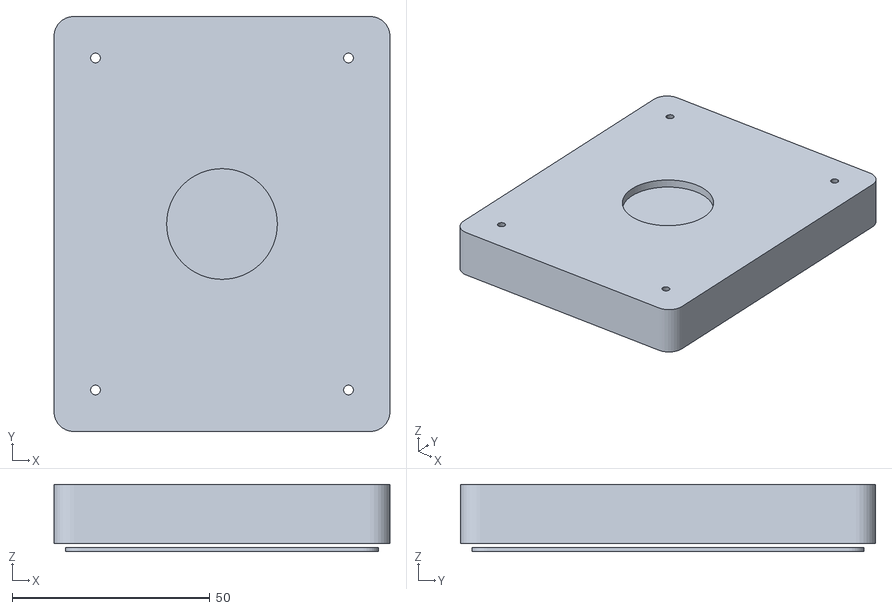
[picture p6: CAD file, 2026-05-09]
enclosure/button-housing - top.stl
85.0 x 105.0 x 17.0

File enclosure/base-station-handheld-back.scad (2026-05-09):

// =============================================================================
// Base Station Handheld - BACK SHELL ONLY
// Ready to export as STL - prints back DOWN
// =============================================================================

// -----------------------------------------------------------------------------
// PARAMETERS (must match front shell!)
// -----------------------------------------------------------------------------

body_width = 70;
body_length = 130;
body_depth = 25;
wall = 2.5;
corner_radius = 8;
edge_radius = 3;
shell_tolerance = 0.3;
lip_depth = 2;

// Components
usbc_width = 12;
usbc_height = 7;

sd_slot_w = 15;
sd_slot_h = 3;
sd_pos_y = 60;

esp32_length = 54;
esp32_width = 25.4;

post_dia = 5;
post_hole_dia = 2.2;

// Calculated
inner_width = body_width - wall*2;
inner_length = body_length - wall*2;
half_depth = body_depth / 2;

// -----------------------------------------------------------------------------
// MODULES
// -----------------------------------------------------------------------------

module rounded_rect_2d(w, l, r) {
    hull() {
        translate([r, r]) circle(r=r, $fn=32);
        translate([w-r, r]) circle(r=r, $fn=32);
        translate([r, l-r]) circle(r=r, $fn=32);
        translate([w-r, l-r]) circle(r=r, $fn=32);
    }
}

module rounded_body(w, l, d, corner_r, edge_r) {
    minkowski() {
        linear_extrude(height=d - edge_r*2)
            offset(r=-edge_r)
                rounded_rect_2d(w, l, corner_r);
        sphere(r=edge_r, $fn=24);
    }
}

module mounting_post(height, outer_d, inner_d) {
    difference() {
        cylinder(h=height, d=outer_d, $fn=24);
        translate([0, 0, -1])
            cylinder(h=height+2, d=inner_d, $fn=16);
    }
}

// -----------------------------------------------------------------------------
// BACK SHELL
// -----------------------------------------------------------------------------

module back_shell() {
    difference() {
        union() {
            intersection() {
                rounded_body(body_width, body_length, body_depth, corner_radius, edge_radius);
                translate([-1, -1, half_depth - 1])
                    cube([body_width+2, body_length+2, half_depth + 2]);
            }

            // Alignment lip
            translate([wall + shell_tolerance, wall + shell_tolerance, half_depth - lip_depth])
                cube([inner_width - shell_tolerance*2, inner_length - shell_tolerance*2, lip_depth]);
        }

        // Hollow inside (stops at back wall - keeps back enclosed)
        translate([wall, wall, half_depth])
            cube([inner_width, inner_length, half_depth - wall*2]);

        // Lip interior
        translate([wall*2, wall*2, half_depth - lip_depth - 1])
            cube([inner_width - wall*2, inner_length - wall*2, lip_depth + 2]);

        // USB-C port (bottom)
        translate([body_width/2 - usbc_width/2, -1, half_depth + (half_depth-wall)/2 - usbc_height/2])
            cube([usbc_width, wall + 2, usbc_height]);

        // SD card slot (right side)
        translate([body_width - wall - 1, sd_pos_y - sd_slot_w/2, half_depth + 3])
            cube([wall + 2, sd_slot_w, sd_slot_h]);

        // Ventilation
        vent_count = 5;
        vent_spacing = 8;
        vent_length = 25;
        for (i = [0:vent_count-1]) {
            translate([body_width/2 - vent_length/2,
                       body_length/2 - (vent_count * vent_spacing)/2 + i * vent_spacing,
                       body_depth - wall - 1])
                cube([vent_length, 3, wall + 2]);
        }

        // Screw holes
        screw_inset = 8;
        translate([screw_inset, screw_inset, half_depth - 1])
            cylinder(h=half_depth + 2, d=post_hole_dia, $fn=16);
        translate([body_width - screw_inset, screw_inset, half_depth - 1])
            cylinder(h=half_depth + 2, d=post_hole_dia, $fn=16);
        translate([screw_inset, body_length - screw_inset, half_depth - 1])
            cylinder(h=half_depth + 2, d=post_hole_dia, $fn=16);
        translate([body_width - screw_inset, body_length - screw_inset, half_depth - 1])
            cylinder(h=half_depth + 2, d=post_hole_dia, $fn=16);
    }

    // Mounting posts
    screw_inset = 8;
    post_h = half_depth - wall - 1;

    translate([screw_inset, screw_inset, half_depth])
        mounting_post(post_h, post_dia, post_hole_dia);
    translate([body_width - screw_inset, screw_inset, half_depth])
        mounting_post(post_h, post_dia, post_hole_dia);
    translate([screw_inset, body_length - screw_inset, half_depth])
        mounting_post(post_h, post_dia, post_hole_dia);
    translate([body_width - screw_inset, body_length - screw_inset, half_depth])
        mounting_post(post_h, post_dia, post_hole_dia);

    // ESP32 rails
    esp_x = body_width/2 - esp32_width/2;
    esp_y = body_length/2 - esp32_length/2 + 10;

    translate([esp_x - 2, esp_y, half_depth])
        cube([3, esp32_length, 4]);
    translate([esp_x + esp32_width - 1, esp_y, half_depth])
        cube([3, esp32_length, 4]);
}

// -----------------------------------------------------------------------------
// RENDER - Positioned for printing (back down on bed)
// -----------------------------------------------------------------------------

translate([0, 0, -half_depth + 1]) back_shell();

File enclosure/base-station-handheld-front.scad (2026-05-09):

// =============================================================================
// Base Station Handheld - FRONT SHELL ONLY
// Ready to export as STL - prints face DOWN
// =============================================================================

// -----------------------------------------------------------------------------
// PARAMETERS (must match back shell!)
// -----------------------------------------------------------------------------

body_width = 70;
body_length = 130;
body_depth = 25;
wall = 2.5;
corner_radius = 8;
edge_radius = 3;
shell_tolerance = 0.3;
lip_depth = 2;

// Components
oled_window_w = 30;
oled_window_h = 16;
oled_pcb_w = 27;
oled_pcb_h = 27;
oled_pos_y = 85;

button_hole_dia = 12;
button1_x = body_width/2 - 15;
button2_x = body_width/2 + 15;
button_y = 45;

led_hole_dia = 5;
led_pos_y = 70;

post_dia = 5;
post_hole_dia = 2.2;

// Calculated
inner_width = body_width - wall*2;
inner_length = body_length - wall*2;
half_depth = body_depth / 2;

// -----------------------------------------------------------------------------
// MODULES
// -----------------------------------------------------------------------------

module rounded_rect_2d(w, l, r) {
    hull() {
        translate([r, r]) circle(r=r, $fn=32);
        translate([w-r, r]) circle(r=r, $fn=32);
        translate([r, l-r]) circle(r=r, $fn=32);
        translate([w-r, l-r]) circle(r=r, $fn=32);
    }
}

module rounded_body(w, l, d, corner_r, edge_r) {
    minkowski() {
        linear_extrude(height=d - edge_r*2)
            offset(r=-edge_r)
                rounded_rect_2d(w, l, corner_r);
        sphere(r=edge_r, $fn=24);
    }
}

module screw_hole(depth, hole_d, head_d) {
    union() {
        translate([0, 0, -1])
            cylinder(h=depth+2, d=hole_d, $fn=16);
        translate([0, 0, depth - 2])
            cylinder(h=3, d1=hole_d, d2=head_d, $fn=16);
    }
}

module button_label(w, h, depth) {
    translate([-w/2, -h/2, 0])
        cube([w, h, depth]);
}

// -----------------------------------------------------------------------------
// FRONT SHELL
// -----------------------------------------------------------------------------

module front_shell() {
    difference() {
        union() {
            intersection() {
                rounded_body(body_width, body_length, body_depth, corner_radius, edge_radius);
                translate([-1, -1, -1])
                    cube([body_width+2, body_length+2, half_depth + lip_depth + 1]);
            }
        }

        translate([wall, wall, wall])
            cube([inner_width, inner_length, half_depth + lip_depth]);

        // OLED window
        translate([body_width/2 - oled_window_w/2, oled_pos_y - oled_window_h/2, -1])
            cube([oled_window_w, oled_window_h, wall + 2]);

        // OLED recess
        translate([body_width/2 - oled_window_w/2 - 2, oled_pos_y - oled_window_h/2 - 2, wall - 1])
            cube([oled_window_w + 4, oled_window_h + 4, 2]);

        // LED hole
        translate([body_width/2, led_pos_y, -1])
            cylinder(h=wall+2, d=led_hole_dia, $fn=16);

        // Button holes
        translate([button1_x, button_y, -1])
            cylinder(h=wall+2, d=button_hole_dia, $fn=32);
        translate([button2_x, button_y, -1])
            cylinder(h=wall+2, d=button_hole_dia, $fn=32);

        // Button labels
        translate([button1_x, button_y - 12, wall - 0.8])
            button_label(14, 6, 1);
        translate([button2_x, button_y - 12, wall - 0.8])
            button_label(14, 6, 1);

        // Screw holes
        screw_inset = 8;
        translate([screw_inset, screw_inset, 0])
            screw_hole(half_depth, post_hole_dia, post_hole_dia + 3);
        translate([body_width - screw_inset, screw_inset, 0])
            screw_hole(half_depth, post_hole_dia, post_hole_dia + 3);
        translate([screw_inset, body_length - screw_inset, 0])
            screw_hole(half_depth, post_hole_dia, post_hole_dia + 3);
        translate([body_width - screw_inset, body_length - screw_inset, 0])
            screw_hole(half_depth, post_hole_dia, post_hole_dia + 3);
    }

    // OLED mounts
    oled_mount_w = oled_pcb_w + 4;
    oled_mount_h = oled_pcb_h + 4;
    translate([body_width/2 - oled_mount_w/2 + 2, oled_pos_y - oled_mount_h/2 + 2, wall])
        cube([2, oled_mount_h - 4, 3]);
    translate([body_width/2 + oled_mount_w/2 - 4, oled_pos_y - oled_mount_h/2 + 2, wall])
        cube([2, oled_mount_h - 4, 3]);
}

// -----------------------------------------------------------------------------
// RENDER - Flipped for printing (face down on bed)
// -----------------------------------------------------------------------------

rotate([180, 0, 0]) translate([0, -body_length, -half_depth - lip_depth]) front_shell();

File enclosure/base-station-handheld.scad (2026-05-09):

// =============================================================================
// Classroom Buzzer Base Station - HANDHELD DESIGN
// Parametric OpenSCAD Design for ABS 3D Printing
// =============================================================================
//
// A compact handheld controller with:
//   - OLED display on the face (visible while holding)
//   - Start/Stop and Reset buttons on top (thumb accessible)
//   - Ergonomic grip shape
//   - USB-C port on bottom for charging/power
//   - SD card slot on side
//
// Usage:
//   1. Adjust parameters below to fit your components
//   2. Render (F6) then Export STL
//   3. Print front and back separately
//
// ABS Print Settings:
//   - Nozzle: 230-250°C
//   - Bed: 90-110°C
//   - Enclosed printer recommended
//   - Infill: 20-30%
//   - Layer height: 0.2mm
//
// =============================================================================

// -----------------------------------------------------------------------------
// MAIN ENCLOSURE PARAMETERS
// -----------------------------------------------------------------------------

// Overall dimensions (like a TV remote / game controller)
body_width = 70;          // X dimension (width in hand)
body_length = 130;        // Y dimension (length, top to bottom)
body_depth = 25;          // Z dimension (thickness)

// Wall thickness
wall = 2.5;               // Wall thickness for ABS durability

// Corner rounding
corner_radius = 8;        // Rounded corners for comfort
edge_radius = 3;          // Edge rounding for grip

// Shell split
shell_tolerance = 0.3;    // Gap between front and back shells
lip_depth = 2;            // How deep the alignment lip goes

// -----------------------------------------------------------------------------
// COMPONENT DIMENSIONS (measure your actual parts!)
// -----------------------------------------------------------------------------

// OLED Display (128x64, 0.96") - on the FACE
oled_window_w = 30;       // Visible window width
oled_window_h = 16;       // Visible window height
oled_pcb_w = 27;          // PCB width for mounting
oled_pcb_h = 27;          // PCB height
oled_pos_y = 85;          // Position from bottom (upper area)

// Control Buttons (on TOP face, thumb accessible)
button_hole_dia = 12;     // Button mounting hole diameter
button1_x = body_width/2 - 15;   // Start/Stop button X
button2_x = body_width/2 + 15;   // Reset button X
button_y = 45;            // Distance from bottom

// SD Card slot (side access)
sd_slot_w = 15;           // SD card opening width
sd_slot_h = 3;            // SD card opening height
sd_pos_y = 60;            // Position from bottom

// USB-C Port (bottom for power)
usbc_width = 12;          // USB-C opening width
usbc_height = 7;          // USB-C opening height

// ESP32-C6-DevKitC-1
esp32_length = 54;        // Length of devkit
esp32_width = 25.4;       // Width of devkit
esp32_height = 10;        // Height including components

// Status LED hole
led_hole_dia = 5;         // Status LED viewing hole
led_pos_y = 70;           // Below OLED

// -----------------------------------------------------------------------------
// MOUNTING PARAMETERS
// -----------------------------------------------------------------------------

post_dia = 5;             // Mounting post diameter
post_hole_dia = 2.2;      // Screw hole diameter (M2.5)
post_height = body_depth - wall*2 - 2;  // Post height

// -----------------------------------------------------------------------------
// ERGONOMIC PARAMETERS
// -----------------------------------------------------------------------------

// Grip contour (makes it comfortable to hold)
grip_indent = 3;          // How deep the grip curves inward
grip_start_y = 10;        // Where grip area starts
grip_end_y = 50;          // Where grip area ends

// Palm swell (back bulges slightly for comfort)
palm_swell = 4;           // Extra thickness at palm area
palm_center_y = 30;       // Center of palm swell

// -----------------------------------------------------------------------------
// CALCULATED VALUES
// -----------------------------------------------------------------------------

inner_width = body_width - wall*2;
inner_length = body_length - wall*2;
inner_depth = body_depth - wall*2;
half_depth = body_depth / 2;

// -----------------------------------------------------------------------------
// MODULES
// -----------------------------------------------------------------------------

// 2D rounded rectangle
module rounded_rect_2d(w, l, r) {
    hull() {
        translate([r, r]) circle(r=r, $fn=32);
        translate([w-r, r]) circle(r=r, $fn=32);
        translate([r, l-r]) circle(r=r, $fn=32);
        translate([w-r, l-r]) circle(r=r, $fn=32);
    }
}

// 3D rounded box with edge rounding
module rounded_body(w, l, d, corner_r, edge_r) {
    minkowski() {
        linear_extrude(height=d - edge_r*2)
            offset(r=-edge_r)
                rounded_rect_2d(w, l, corner_r);
        sphere(r=edge_r, $fn=24);
    }
}

// Mounting post
module mounting_post(height, outer_d, inner_d) {
    difference() {
        cylinder(h=height, d=outer_d, $fn=24);
        translate([0, 0, -1])
            cylinder(h=height+2, d=inner_d, $fn=16);
    }
}

// Screw hole (countersunk)
module screw_hole(depth, hole_d, head_d) {
    union() {
        // Shaft
        translate([0, 0, -1])
            cylinder(h=depth+2, d=hole_d, $fn=16);
        // Countersink
        translate([0, 0, depth - 2])
            cylinder(h=3, d1=hole_d, d2=head_d, $fn=16);
    }
}

// Button label recess
module button_label(w, h, depth) {
    translate([-w/2, -h/2, 0])
        cube([w, h, depth]);
}

// -----------------------------------------------------------------------------
// FRONT SHELL (with display)
// -----------------------------------------------------------------------------

module front_shell() {
    difference() {
        union() {
            // Main body - front half
            intersection() {
                rounded_body(body_width, body_length, body_depth, corner_radius, edge_radius);
                translate([-1, -1, -1])
                    cube([body_width+2, body_length+2, half_depth + lip_depth + 1]);
            }
        }

        // Hollow out inside
        translate([wall, wall, wall])
            cube([inner_width, inner_length, half_depth + lip_depth]);

        // --- CUTOUTS ---

        // OLED window (on face)
        translate([body_width/2 - oled_window_w/2, oled_pos_y - oled_window_h/2, -1])
            cube([oled_window_w, oled_window_h, wall + 2]);

        // OLED mounting recess (slightly larger than window)
        translate([body_width/2 - oled_window_w/2 - 2, oled_pos_y - oled_window_h/2 - 2, wall - 1])
            cube([oled_window_w + 4, oled_window_h + 4, 2]);

        // Status LED hole
        translate([body_width/2, led_pos_y, -1])
            cylinder(h=wall+2, d=led_hole_dia, $fn=16);

        // Button holes (on top surface - angled for ergonomics)
        translate([button1_x, button_y, -1])
            cylinder(h=wall+2, d=button_hole_dia, $fn=32);
        translate([button2_x, button_y, -1])
            cylinder(h=wall+2, d=button_hole_dia, $fn=32);

        // Button label recesses
        translate([button1_x, button_y - 12, wall - 0.8])
            button_label(14, 6, 1);
        translate([button2_x, button_y - 12, wall - 0.8])
            button_label(14, 6, 1);

        // Screw holes for assembly (4 corners)
        screw_inset = 8;
        translate([screw_inset, screw_inset, 0])
            screw_hole(half_depth, post_hole_dia, post_hole_dia + 3);
        translate([body_width - screw_inset, screw_inset, 0])
            screw_hole(half_depth, post_hole_dia, post_hole_dia + 3);
        translate([screw_inset, body_length - screw_inset, 0])
            screw_hole(half_depth, post_hole_dia, post_hole_dia + 3);
        translate([body_width - screw_inset, body_length - screw_inset, 0])
            screw_hole(half_depth, post_hole_dia, post_hole_dia + 3);
    }

    // OLED mounting posts (inside)
    oled_mount_w = oled_pcb_w + 4;
    oled_mount_h = oled_pcb_h + 4;
    translate([body_width/2 - oled_mount_w/2 + 2, oled_pos_y - oled_mount_h/2 + 2, wall])
        cube([2, oled_mount_h - 4, 3]);
    translate([body_width/2 + oled_mount_w/2 - 4, oled_pos_y - oled_mount_h/2 + 2, wall])
        cube([2, oled_mount_h - 4, 3]);
}

// -----------------------------------------------------------------------------
// BACK SHELL
// -----------------------------------------------------------------------------

module back_shell() {
    difference() {
        union() {
            // Main body - back half
            intersection() {
                rounded_body(body_width, body_length, body_depth, corner_radius, edge_radius);
                translate([-1, -1, half_depth - 1])
                    cube([body_width+2, body_length+2, half_depth + 2]);
            }
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

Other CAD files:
enclosure/button-housing v2.stl
enclosure/base-station-housing.scad
enclosure/button-housing-bottom.scad
enclosure/button-housing-top.scad
enclosure/button-housing-top.stl
enclosure/button-housing.scad

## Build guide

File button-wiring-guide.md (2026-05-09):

# Complete Button Unit Wiring Guide

## Overview
This guide covers the complete wiring for a wireless quiz buzzer button unit including ESP32-C6, OLED display, arcade button, 3W speaker for audio feedback, battery management, and power control.

**Current Implementation Status:** This guide reflects the actively developed battery-powered version with audio feedback, voltage monitoring, and OLED display.

## Components Required (Per Button Unit)

### Main Components:
- 1x ESP32-C6-DevKitC-1 (or ESP32-C6-DevKitM-1)
- 1x 0.91" OLED Display (128x32 I2C SSD1306)
- 1x Large Arcade Button (60mm LED illuminated)
- 1x 3W 8Ω Speaker (for audio feedback - buzzer sounds, victory tunes)
- 1x 503035 LiPo Battery (3.7V 500mAh) - or larger capacity like 18650
- 1x TP4056 Battery Charging Module (with protection)
- 1x MT3608 DC-DC Boost Converter (3.7V → 5V for ESP32)
- 1x MT3608 DC-DC Boost Converter (3.7V → 12V for button LED) - Optional
- 1x Toggle Switch (SPST, for main power)
- 1x 2N2222 NPN Transistor (for LED control) - Optional
- 1x Power Indicator LED (3mm or 5mm, any color)
- 1x USB-C charging port (optional - can use TP4056's micro USB)

### Resistors:
- 1x 10kΩ resistor (button pull-down)
- 1x 1kΩ resistor (transistor base)
- 1x 1kΩ resistor (power indicator LED)
- 1x 330Ω resistor (LED current limiting)
- 2x 47kΩ resistor (battery voltage divider)

### Wiring Materials:
- 22-24 AWG stranded wire (various colors)
- Heat shrink tubing
- Solder and flux
- Perfboard or PCB (optional)

---

## Pin Assignments (ESP32-C6)

| Function | ESP32-C6 Pin | Wire Color | Notes |
|---|---|---|---|
| **I2C SDA** | GPIO6 | Blue | OLED Display Data |
| **I2C SCL** | GPIO7 | Yellow | OLED Display Clock |
| **Button Input** | GPIO15 | Green | Arcade button signal |
| **Status LED** | GPIO2 | Orange | Built-in LED status indicator |
| **Speaker Output** | GPIO8 | Purple | PWM audio feedback (3W 8Ω speaker) |
| **Battery Monitor** | GPIO1/A0 | White | Battery voltage sensing via ADC |
| **LED Control** | GPIO4 | Red/White | (Optional) Controls button LED via transistor |
| **Power (5V)** | VIN | Red | From boost converter |
| **Ground** | GND | Black | Common ground |
| **3.3V** | 3V3 | Red | For pull-up if needed |

### Important Pin Selection Notes

**Why GPIO1 for Battery Monitoring?**
- GPIO0 is a **strapping pin** on ESP32-C6 that affects boot mode
- Connecting voltage dividers to GPIO0 can cause boot failures
- GPIO1 is ADC-capable and has no boot-time conflicts
- The voltage divider (two 47kΩ resistors) safely divides battery voltage by 2

**ADC-Capable Pins on ESP32-C6:**
- **ADC1:** GPIO0-GPIO7 (use GPIO1-5 for analog sensing to avoid strapping pins)
- GPIO18-GPIO23 are **NOT** ADC-capable and cannot be used for battery voltage sensing

**Audio Output Requirements:**
- Speaker connects directly to GPIO8 (PWM capable)
- No amplifier needed for 3W 8Ω speaker
- ESP32 can drive the speaker directly with sufficient volume

---

## Complete Wiring Diagram

```
ESP32-C6 BUTTON UNIT WIRING
============================

OLED Display (0.91" 128x32 I2C):
  ESP32 GPIO6 (SDA) ──────────────── OLED SDA
  ESP32 GPIO7 (SCL) ──────────────── OLED SCL
  ESP32 3.3V ─────────────────────── OLED VCC
  ESP32 GND ──────────────────────── OLED GND

Arcade Button Connection:
  Button NO (Normally Open) ────────── ESP32 3.3V
  Button COM (Common) ───────────────── ESP32 GPIO15
  10kΩ Resistor ─────────────────────── Between GPIO15 and GND

Speaker Connection (3W 8Ω):
  ESP32 GPIO8 ────────────────────── Speaker + (Positive)
  ESP32 GND ──────────────────────── Speaker - (Negative)
  Note: Direct connection OK for 3W speaker, ESP32 PWM can drive it

Status LED (Built-in):
  ESP32 GPIO2 ────────────────────── Built-in LED (onboard)

Button LED Control Circuit:
  ESP32 GPIO4 ──[1kΩ]── 2N2222 Base
  2N2222 Collector ─────────────────── 12V Boost OUT+
  2N2222 Emitter ───[330Ω]─────────── Button LED + (Anode)
  Button LED - (Cathode) ───────────── Common GND

Power Management System:
  503035 LiPo Battery + ────────────── TP4056 BAT+
  503035 LiPo Battery - ────────────── TP4056 BAT-

  TP4056 OUT+ ──── Power Switch ───── 5V Boost IN+ & 12V Boost IN+
  TP4056 OUT- ──────────────────────── 5V Boost IN- & 12V Boost IN-

  5V Boost OUT+ (adjusted to 5.0V) ──── ESP32 VIN
  5V Boost GND ─────────────────────── Common GND

  12V Boost OUT+ (adjusted to 12V) ──── LED Control Circuit
  12V Boost GND ────────────────────── Common GND

Power Indicator LED:
  TP4056 OUT+ (after switch) ──[1kΩ]── Power LED Anode (+)
  Power LED Cathode (-) ────────────── Common GND

Battery Voltage Monitoring:
  TP4056 OUT+ ──[47kΩ]─┬─[47kΩ]── GND
                        │
                   ESP32 GPIO1 (A0)

Charging Circuit:
  USB-C/Micro USB 5V ─────────────── TP4056 IN+
  USB-C/Micro USB GND ────────────── TP4056 IN-

Common Ground Network:
  ████ ALL THESE MUST BE CONNECTED ████
  - 503035 LiPo Battery -
  - TP4056 OUT- and GND
  - Both Boost Converter GND
  - ESP32 GND
  - OLED GND
  - Button circuit GND
  - LED circuit GND
  - Power Indicator LED -
  ████████████████████████████████████
```

---

## Step-by-Step Assembly Instructions

### 1. Prepare the Boost Converters

**5V Boost Converter (for ESP32):**
1. Connect multimeter to output terminals
2. Power the input with 3.7V (or use a bench supply)
3. Slowly adjust the potentiometer until output reads exactly 5.0V
4. Mark with label "ESP32 - 5.0V"

**12V Boost Converter (for LED):**
1. Connect multimeter to output terminals
2. Power the input with 3.7V
3. Adjust potentiometer until output reads 12.0V (or voltage required by your LED)
4. Mark with label "LED - 12V"

### 2. Wire the Power System

1. **Battery Connection:**
   ```
   503035 LiPo Battery + (Red) ──── TP4056 BAT+
   503035 LiPo Battery - (Black) ── TP4056 BAT-
   ```

2. **Power Switch and Indicator LED:**
   ```
   TP4056 OUT+ ──── Switch Terminal 1
   Switch Terminal 2 ──── Both Boost Converters IN+ & Power LED (via 1kΩ)
   Power LED Anode (+) ──[1kΩ]── TP4056 OUT+ (after switch)
   Power LED Cathode (-) ──────── Common GND
   ```

3. **Boost Converters:**
   ```
   TP4056 OUT- ──── Both Boost Converters IN-
   5V Boost OUT+ ──── ESP32 VIN
   12V Boost OUT+ ──── LED Control Circuit
   All GND ──── Common Ground Bus
   ```

### 3. Wire the ESP32 Connections

1. **OLED Display:**
   ```
   ESP32 GPIO6 ──── OLED SDA (Blue wire)
   ESP32 GPIO7 ──── OLED SCL (Yellow wire)
   ESP32 3.3V ──── OLED VCC (Red wire)
   ESP32 GND ──── OLED GND (Black wire)
   ```

2. **Button Input:**
   ```
   Button NO ──── ESP32 3.3V (Red wire)
   Button COM ──── ESP32 GPIO15 (Green wire)
   10kΩ Resistor ──── Between GPIO15 and GND
   ```

3. **Speaker (3W 8Ω Audio Feedback):**
   ```
   ESP32 GPIO8 ──── Speaker + (Purple wire)
   ESP32 GND ──── Speaker - (Black wire)
   ```

4. **Status LED (Built-in):**
   ```
   ESP32 GPIO2 ──── Built-in LED (onboard, no external wiring needed)
   ```

5. **Battery Monitoring:**
   ```
   TP4056 OUT+ ──[47kΩ]─┬─[47kΩ]── GND
                         │
                    ESP32 GPIO1 (White wire)
   ```

6. **LED Control (Optional - for arcade button illumination):**
   ```
   ESP32 GPIO4 ──[1kΩ]── 2N2222 Base (Orange wire)
   ```

### 7. Build the LED Control Circuit (Optional)

```
LED Control Circuit Assembly:
           12V+
            │
            │
    ┌───────┴──────┐
    │   2N2222     │
    │   Collector  │
    │       │      │
    │   ┌───┴───┐  │
    │   │ 330Ω  │  │  
    │   └───┬───┘  │
    │       │      │
    │   Button LED+│
    │       │      │
    │   Button LED-│
    │       │      │
    │   ┌───┴───┐  │
    │   │  GND  │  │
    │   └───────┘  │
    │              │
    │     Base     │
    │   ┌───┴───┐  │
    │   │  1kΩ  │  │
    │   └───┬───┘  │
    │       │      │
    └───────┴──────┘
         GPIO4
```

---

## Enclosure and Mounting

### Recommended Enclosure Layout:
```
     ┌─────────────────────────────────┐
     │  ┌─────────┐    ┌─────────────┐ │
     │  │ ESP32-C6│    │   TP4056    │ │
     │  │         │    │  Charging   │ │
     │  └─────────┘    └─────────────┘ │
     │                                 │
     │  ┌─────────┐    ┌─────────────┐ │
     │  │  OLED   │    │ 5V Boost    │ │
     │  │ Display │    │ Converter   │ │
     │  └─────────┘    └─────────────┘ │
     │                                 │
     │     ┌───────────────────┐       │
     │     │    18650 Battery  │       │
     │     │     Holder        │       │
     │     └───────────────────┘       │
     │                                 │
     │  ┌─────────────┐  ┌───────────┐ │
     │  │ 12V Boost   │  │   Power   │ │
     │  │ Converter   │  │  Switch   │ │
     │  └─────────────┘  └───────────┘ │
     └─────────────────────────────────┘
                    │
              ┌─────────────┐
              │   Arcade    │
              │   Button    │
              │  (60mm LED) │
              └─────────────┘
```

### Mounting Points:
1. **Arcade Button:** Mount through enclosure top with retaining nut
2. **OLED Display:** Mount behind small window or cutout
3. **Power Switch:** Side-mounted toggle switch
4. **Charging Port:** Use TP4056's micro USB or add external USB-C
5. **ESP32:** Secure with standoffs or mounting posts

---

## Testing and Calibration

### Pre-Power Testing:
1. **Continuity Check:** Verify all ground connections with multimeter
2. **Voltage Check:** Test boost converter outputs before connecting ESP32
3. **Isolation Check:** Ensure no shorts between power rails

### Power-On Testing:
1. **Battery Voltage:** Check TP4056 output voltage (should be 3.7-4.2V)
2. **Boost Converters:** Verify 5V and 12V outputs under load
3. **ESP32 Power:** Confirm 5V at VIN pin and 3.3V at 3V3 pin

### Software Testing:
1. **Upload Code:** Flash the button.ino sketch
2. **Serial Monitor:** Check for MAC address and battery voltage readings (GPIO1 ADC)
3. **Button Test:** Press button and verify GPIO15 reading
4. **Speaker Test:** Verify startup sound plays on GPIO8
5. **Status LED Test:** Check GPIO2 built-in LED patterns
6. **OLED Test:** Check display shows team name, battery %, and game status
7. **Battery Monitor:** Verify battery voltage and percentage display correctly

### ESP-NOW Pairing:
1. **Get MAC Address:** Note the button's MAC from Serial Monitor
2. **Base Station Config:** Add button MAC to base station team configuration
3. **Connection Test:** Verify heartbeat communication and button presses

---

## Troubleshooting Guide

### Power Issues:
| Problem | Possible Cause | Solution |
|---|---|---|
| ESP32 won't start | No 5V power | Check boost converter output and connections |
| Battery drains quickly | Short circuit | Check all connections with multimeter |
| Won't charge | TP4056 wiring | Verify charging circuit connections |

### Communication Issues:
| Problem | Possible Cause | Solution |
|---|---|---|
| No ESP-NOW connection | Wrong MAC address | Re-check MAC addresses in configuration |
| OLED blank | I2C wiring | Verify SDA/SCL connections and address |
| Button not responding | GPIO15 wiring | Check button and pull-down resistor |

### LED Issues:
| Problem | Possible Cause | Solution |
|---|---|---|
| LED won't light | Transistor circuit | Check transistor orientation and connections |
| LED too dim | Wrong voltage | Verify 12V boost output and current limiting |
| LED always on | Transistor fault | Check GPIO4 control signal and transistor |

---

## Safety Notes

⚠️ **Important Safety Guidelines:**

1. **Battery Safety:**
   - Use only quality 18650 batteries with protection circuits
   - Never short circuit battery terminals
   - Monitor charging temperature

2. **Electrical Safety:**
   - Double-check all connections before powering on
   - Use appropriate wire gauges for current loads
   - Insulate all connections properly

3. **Component Protection:**
   - Ensure correct voltage levels before connecting ESP32
   - Use ESD precautions when handling electronics
   - Verify polarity on all power connections

---

## Bill of Materials (BOM)

| Component | Quantity | Part Number/Specs | Estimated Cost |
|---|---|---|---|
| ESP32-C6-DevKitC-1 | 1 | Espressif ESP32-C6-DevKitC-1 | $15 |
| OLED Display | 1 | 0.91" 128x32 I2C SSD1306 | $8 |
| Arcade Button | 1 | 60mm LED illuminated | $12 |
| 3W Speaker | 1 | 3W 8Ω speaker for audio feedback | $6 |
| 503035 LiPo Battery | 1 | 3.7V 500mAh (or 18650 for longer runtime) | $5-10 |
| TP4056 Module | 1 | With protection circuit | $3 |
| MT3608 Boost (5V) | 1 | DC-DC Step-up converter for ESP32 | $2 |
| MT3608 Boost (12V) | 1 | DC-DC Step-up converter for LED (optional) | $2 |
| Toggle Switch | 1 | SPST 3A rated | $2 |
| Power Indicator LED | 1 | 3mm or 5mm, any color | $0.50 |
| 2N2222 Transistor | 1 | NPN switching transistor (optional) | $0.50 |
| Resistors | 6 | 10kΩ, 1kΩ(2x), 330Ω, 47kΩ(2x) | $1 |
| Wire & Connectors | 1 | 22AWG stranded, various colors | $5 |
| Enclosure | 1 | Plastic project box | $10 |
| **Total per unit** | | | **~$72.00** |

**Note:** Items marked "optional" are for arcade button LED illumination. The core functionality (button press detection, audio feedback, OLED display, battery monitoring) works without them.

---

This complete wiring guide provides everything needed to build a professional wireless quiz buzzer button with display, battery management, and robust construction.

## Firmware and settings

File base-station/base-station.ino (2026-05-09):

#include <WiFi.h>
#include <WebServer.h>
#include <esp_now.h>
#include <Wire.h>
#include <Adafruit_GFX.h>
#include <Adafruit_SSD1306.h>
#include <FS.h>
#include <SD.h>
#include <SPI.h>
#include "base-secret.h"

// Display configuration
#define SCREEN_WIDTH 128
#define SCREEN_HEIGHT 64
#define OLED_RESET -1
Adafruit_SSD1306 display(SCREEN_WIDTH, SCREEN_HEIGHT, &Wire, OLED_RESET);

// Pin definitions for ESP32-C6
#define I2C_SDA 6
#define I2C_SCL 7
#define SD_MOSI 23
#define SD_MISO 19
#define SD_SCK 18
#define SD_CS 5

// Physical button pins
#define BTN_START_STOP 10  // GPIO10 - Start/Stop game (with internal pull-up)
#define BTN_RESET 1        // GPIO1 - Reset round (with internal pull-up)

// Timing constants
#define HEARTBEAT_TIMEOUT_MS 30000      // Mark button offline after 30 seconds
#define DISPLAY_CYCLE_INTERVAL_MS 2000  // Cycle through teams every 2 seconds
#define DEBOUNCE_DELAY_MS 250           // Button debounce delay

// Message protocol constants
#define MESSAGE_SIZE 32                 // ESP-NOW message size
#define TEAM_NAME_MAX_LENGTH 29         // Max team name in message (+ null terminator)

// Game status codes (sent to buttons)
#define STATUS_GAME_STOPPED 0
#define STATUS_WINNER 1
#define STATUS_LOCKED_OUT 2
#define STATUS_GAME_READY 3

// WiFi credentials (defaults from secret file, can be changed via settings)
String ap_ssid = WIFI_SSID;
String ap_password = WIFI_PASSWORD;
bool wifiSettingsChanged = false;  // Flag to show reboot needed

// Web server
WebServer server(80);

// Game state
bool gameActive = false;
int winnerTeam = -1;
unsigned long gameStartTime = 0;
unsigned long winnerTime = 0;

// Countdown settings (saved to SD card)
bool countdownEnabled = false;        // Off by default
int countdownSeconds = 3;             // Configurable: 1-5 seconds

// Countdown state (runtime only)
bool countdownActive = false;
unsigned long countdownStartTime = 0;
int countdownStep = 0;                // Current step: 3, 2, 1, 0 (BUZZ!)

// Audio settings
bool audioMuted = false;

// Button debounce variables
unsigned long lastBtnStartStopPress = 0;
unsigned long lastBtnResetPress = 0;
bool lastBtnStartStopState = HIGH;
bool lastBtnResetState = HIGH;

// Team configuration
#define MAX_TEAMS 9  // Maximum number of teams (can be 1-9)
struct Team {
  String name;
  uint8_t mac[6];
  bool isConfigured;
  bool isOnline;
  unsigned long lastSeen;
  bool isMuted;
};

Team teams[MAX_TEAMS];

// Pending buttons (auto-discovered but not yet configured)
#define MAX_PENDING 5
struct PendingButton {
  uint8_t mac[6];
  unsigned long lastSeen;
  bool active;
};

PendingButton pendingButtons[MAX_PENDING];

// SD card available flag
bool sdCardAvailable = false;

// HTML escape function to prevent XSS attacks
String escapeHtml(String input) {
  input.replace("&", "&amp;");
  input.replace("<", "&lt;");
  input.replace(">", "&gt;");
  input.replace("\"", "&quot;");
  input.replace("'", "&#39;");
  return input;
}

// Initialize pending buttons array
void initializePendingButtons() {
  for (int i = 0; i < MAX_PENDING; i++) {
    pendingButtons[i].active = false;
    pendingButtons[i].lastSeen = 0;
    memset(pendingButtons[i].mac, 0, 6);
  }
}

// Check if MAC is already a configured team
bool isConfiguredTeam(const uint8_t* mac) {
  for (int i = 0; i < MAX_TEAMS; i++) {
    if (teams[i].isConfigured) {
      bool match = true;
      for (int j = 0; j < 6; j++) {
        if (teams[i].mac[j] != mac[j]) {
          match = false;
          break;
        }
      }
      if (match) return true;
    }
  }
  return false;
}

// Check if MAC is already in pending list
int findPendingButton(const uint8_t* mac) {
  for (int i = 0; i < MAX_PENDING; i++) {
    if (pendingButtons[i].active) {
      bool match = true;
      for (int j = 0; j < 6; j++) {
        if (pendingButtons[i].mac[j] != mac[j]) {
          match = false;
          break;
        }
      }
      if (match) return i;
    }
  }
  return -1;
}

// Add button to pending list (auto-discovery)
void addToPending(const uint8_t* mac) {
  // Already in pending?
  int existing = findPendingButton(mac);
  if (existing >= 0) {
    pendingButtons[existing].lastSeen = millis();
    return;
  }

  // Find empty slot
  for (int i = 0; i < MAX_PENDING; i++) {
    if (!pendingButtons[i].active) {
      memcpy(pendingButtons[i].mac, mac, 6);
      pendingButtons[i].lastSeen = millis();
      pendingButtons[i].active = true;
      Serial.printf("Auto-discovered new button: %02X:%02X:%02X:%02X:%02X:%02X\n",
        mac[0], mac[1], mac[2], mac[3], mac[4], mac[5]);
      return;
    }
  }

  // No empty slot - replace oldest
  int oldest = 0;
  for (int i = 1; i < MAX_PENDING; i++) {
    if (pendingButtons[i].lastSeen < pendingButtons[oldest].lastSeen) {
      oldest = i;
    }
  }
  memcpy(pendingButtons[oldest].mac, mac, 6);
  pendingButtons[oldest].lastSeen = millis();
  pendingButtons[oldest].active = true;
}

// Format MAC address as string
String formatMac(const uint8_t* mac) {
  char buf[18];
  sprintf(buf, "%02X:%02X:%02X:%02X:%02X:%02X", mac[0], mac[1], mac[2], mac[3], mac[4], mac[5]);
  return String(buf);
}

// Helper function to build and send status message to a specific team
// Message format:
//   Byte 0: Status code (0=stopped, 1=winner, 2=locked, 3=ready)
//   Byte 1: Mute flag (0=unmuted, 1=muted)
//   Bytes 2-3: Response time in ms (uint16_t, little-endian) - only valid for winner
//   Bytes 4-31: Team name (up to 27 chars + null terminator)
void sendStatusMessageToTeam(int teamIndex) {
  if (teamIndex < 0 || teamIndex >= MAX_TEAMS || !teams[teamIndex].isConfigured) {
    return;
  }

  uint8_t message[MESSAGE_SIZE];
  memset(message, 0, sizeof(message));

  // Determine current game status for this team
  if (!gameActive) {
    message[0] = STATUS_GAME_STOPPED;
  } else if (winnerTeam == -1) {
    message[0] = STATUS_GAME_READY;
  } else if (winnerTeam == teamIndex) {
    message[0] = STATUS_WINNER;
  } else {
    message[0] = STATUS_LOCKED_OUT;
  }

  // Add individual mute flag at byte 1 (individual team mute OR global mute)
  message[1] = (audioMuted || teams[teamIndex].isMuted) ? 1 : 0;

  // Add response time at bytes 2-3 (uint16_t, little-endian)
  // Only meaningful for winner, but we send it anyway for simplicity
  uint16_t responseTimeMs = (winnerTime > 65535) ? 65535 : (uint16_t)winnerTime;
  message[2] = responseTimeMs & 0xFF;         // Low byte
  message[3] = (responseTimeMs >> 8) & 0xFF;  // High byte

  // Add team name starting at byte 4 (max 27 chars + null terminator)
  String teamName = teams[teamIndex].name;
  if (teamName.length() > 27) {
    teamName = teamName.substring(0, 27);
  }
  strcpy((char*)&message[4], teamName.c_str());

  // Debug: Print what we're about to send
  Serial.printf("Sending to Team %d (%s): status=%d, muted=%d\n",
    teamIndex + 1, teams[teamIndex].name.c_str(), message[0], message[1]);

  // Add button as peer if not already added
  esp_now_peer_info_t peerInfo;
  memset(&peerInfo, 0, sizeof(peerInfo));
  memcpy(peerInfo.peer_addr, teams[teamIndex].mac, 6);
  peerInfo.channel = 1;  // Must match AP channel
  peerInfo.encrypt = false;
  peerInfo.ifidx = WIFI_IF_AP;  // Use AP interface

  if (!esp_now_is_peer_exist(teams[teamIndex].mac)) {
    esp_err_t addResult = esp_now_add_peer(&peerInfo);
    Serial.printf("Adding peer: %s\n", (addResult == ESP_OK) ? "SUCCESS" : "FAILED");
  }

  // Send message
  esp_err_t sendResult = esp_now_send(teams[teamIndex].mac, message, sizeof(message));
  Serial.printf("Send result: %s\n", (sendResult == ESP_OK) ? "OK" : "ERROR");
}

void setup() {
  Serial.begin(115200);
  Serial.println("Base Station Starting...");

  // Initialize team structure with defaults
  initializeTeams();
  initializePendingButtons();

  // Initialize I2C
  Wire.begin(I2C_SDA, I2C_SCL);
  
  // Initialize display
  if (display.begin(SSD1306_SWITCHCAPVCC, 0x3C)) {
    display.clearDisplay();
    display.setTextSize(1);
    display.setTextColor(SSD1306_WHITE);
    display.setCursor(0, 0);
    display.println("Starting...");
    display.display();
    delay(1000);
  }
  
  // Initialize SD card
  SPI.begin(SD_SCK, SD_MISO, SD_MOSI, SD_CS);
  delay(200);
  
  if (SD.begin(SD_CS)) {
    sdCardAvailable = true;
    loadConfig(); // Load team configuration from SD card
    
    // Update display to show config loaded
    display.clearDisplay();
    display.setCursor(0, 0);
    display.println("Config Loaded!");
    display.display();
    delay(1000);
  } else {
    sdCardAvailable = false;
    
    // Update display to show no SD card
    display.clearDisplay();
    display.setCursor(0, 0);
    display.println("No SD Card");
    display.println("Using defaults");
    display.display();
    delay(1000);
  }
  
  // Start WiFi Access Point with ESP-NOW support
  WiFi.mode(WIFI_AP_STA);  // Need STA mode for ESP-NOW
  delay(100);

  // Set WiFi AP on channel 1 for ESP-NOW compatibility
  if (WiFi.softAP(ap_ssid.c_str(), ap_password.c_str(), 1)) {
    // WiFi started successfully
    display.clearDisplay();
    display.setCursor(0, 0);
    display.println("WiFi OK");
    display.display();
    delay(500);
  } else {
    // WiFi failed - show error on display
    display.clearDisplay();
    display.setCursor(0, 0);
    display.println("WiFi Failed!");
    display.display();
  }
  
  // Initialize ESP-NOW
  if (esp_now_init() != ESP_OK) {
    display.clearDisplay();
    display.setCursor(0, 0);
    display.println("ESP-NOW Failed!");
    display.display();
    delay(2000);
  } else {
    // Register callbacks for receiving and sending data
    esp_now_register_recv_cb(onDataRecv);
    esp_now_register_send_cb(onDataSent);
    
    display.clearDisplay();
    display.setCursor(0, 0);
    display.println("ESP-NOW Ready");
    display.display();
    delay(500);
  }
  
  // Setup web server
  server.on("/", handleRoot);
  server.on("/settings", handleSettings);
  server.on("/start", handleStart);
  server.on("/reset", handleReset);
  server.on("/stop", handleStop);
  server.on("/save", handleSave);
  server.on("/mute", handleMute);
  server.on("/unmute", handleUnmute);
  server.on("/mute-team", handleMuteTeam);
  server.on("/unmute-team", handleUnmuteTeam);
  server.on("/add-pending", handleAddPending);
  server.on("/remove-team", handleRemoveTeam);
  server.on("/save-settings", handleSaveSettings);
  server.on("/reboot", handleReboot);
  server.on("/api/status", handleApiStatus);
  server.begin();
  
  // Initialize physical buttons with pull-up resistors
  pinMode(BTN_START_STOP, INPUT_PULLUP);
  pinMode(BTN_RESET, INPUT_PULLUP);

  // Read initial button states to prevent false triggers at boot
  delay(50); // Small delay to let pins settle
  lastBtnStartStopState = digitalRead(BTN_START_STOP);
  lastBtnResetState = digitalRead(BTN_RESET);

  // Blink LED to show ready
  pinMode(LED_BUILTIN, OUTPUT);
  for (int i = 0; i < 3; i++) {
    digitalWrite(LED_BUILTIN, HIGH);
    delay(200);
    digitalWrite(LED_BUILTIN, LOW);
    delay(200);
  }

  // Show normal interface after initialization
  updateDisplay();
}

void loop() {
  server.handleClient();

  // Process countdown timer
  if (countdownActive) {
    unsigned long elapsed = millis() - countdownStartTime;
    int newStep = countdownSeconds - (elapsed / 1000);

    if (newStep != countdownStep) {
      countdownStep = newStep;
      Serial.printf("Countdown: %d\n", countdownStep);
      updateDisplay();
    }

    // Countdown finished - start the game
    if (elapsed >= (countdownSeconds * 1000)) {
      Serial.println("Countdown complete - starting game!");
      startGameNow();
    }
  }

  // Handle physical button presses
  handlePhysicalButtons();

  // Check for button timeouts (mark offline if not seen recently)
  unsigned long currentTime = millis();
  for (int i = 0; i < MAX_TEAMS; i++) {
    if (teams[i].isConfigured && teams[i].isOnline) {
      if (currentTime - teams[i].lastSeen > HEARTBEAT_TIMEOUT_MS) {
        teams[i].isOnline = false;
      }
    }
  }

  delay(2);
}

// ESP-NOW callback for send status
void onDataSent(const wifi_tx_info_t *tx_info, esp_now_send_status_t status) {
  Serial.printf("ESP-NOW Send Status: %s\n", (status == ESP_NOW_SEND_SUCCESS) ? "SUCCESS" : "FAIL");
}

// ESP-NOW callback function for receiving button presses
void onDataRecv(const esp_now_recv_info *recv_info, const uint8_t *incomingData, int len) {
  if (len < 1) return;

  // Find which team this MAC address belongs to
  int teamIndex = -1;
  for (int i = 0; i < MAX_TEAMS; i++) {
    if (teams[i].isConfigured) {
      bool macMatch = true;
      for (int j = 0; j < 6; j++) {
        if (teams[i].mac[j] != recv_info->src_addr[j]) {
          macMatch = false;
          break;
        }
      }
      if (macMatch) {
        teamIndex = i;
        teams[i].isOnline = true;
        teams[i].lastSeen = millis();
        break;
      }
    }
  }

  // Unknown button - add to pending list for auto-discovery
  if (teamIndex == -1) {
    addToPending(recv_info->src_addr);
    return;
  }

  uint8_t messageType = incomingData[0];

  if (messageType == 1) { // Button press
    handleButtonPress(teamIndex);
  } else if (messageType == 2) { // Heartbeat/status
    // Send current status and team name back to this specific button
    sendTeamStatusUpdate(teamIndex);
  }
}

void handleButtonPress(int teamIndex) {
  if (!gameActive) return; // Game not active
  if (winnerTeam >= 0) return; // Already have a winner
  
  // This team wins!
  winnerTeam = teamIndex;
  winnerTime = millis() - gameStartTime;
  
  // Log to SD card
  logBuzzerEvent(teamIndex, winnerTime);
  
  // Send responses to all configured buttons
  sendButtonResponses();
  
  // Update display
  updateDisplay();
}

// Display cycling variables
unsigned long lastDisplayUpdate = 0;
int currentDisplayTeam = 0;

// Helper: Get team status character for scoreboard
char getTeamStatusChar(int idx) {
  if (!teams[idx].isConfigured) return '-';
  if (winnerTeam == idx) return '*';  // Star for winner
  if (teams[idx].isOnline) return 'O';  // Filled circle (will be ●)
  return 'o';  // Empty circle (will be ○)
}

// Helper: Count configured teams
int countConfiguredTeams() {
  int count = 0;
  for (int i = 0; i < MAX_TEAMS; i++) {
    if (teams[i].isConfigured) count++;
  }
  return count;
}

// Helper: Count online teams
int countOnlineTeams() {
  int count = 0;
  for (int i = 0; i < MAX_TEAMS; i++) {
    if (teams[i].isConfigured && teams[i].isOnline) count++;
  }
  return count;
}

void updateDisplay() {
  display.clearDisplay();
  display.setTextSize(1);
  display.setTextColor(SSD1306_WHITE);
  display.setCursor(0, 0);

  // --- COUNTDOWN MODE ---
  if (countdownActive) {
    display.setTextSize(4);  // Large countdown number
    String text;
    if (countdownStep > 0) {
      text = String(countdownStep);
    } else {
      text = "GO!";
    }
    // Center the text
    int16_t x1, y1;
    uint16_t w, h;
    display.getTextBounds(text.c_str(), 0, 0, &x1, &y1, &w, &h);
    display.setCursor((SCREEN_WIDTH - w) / 2, (SCREEN_HEIGHT - h) / 2);
    display.print(text);
    display.display();
    return;
  }

  // --- GAME ACTIVE MODE ---
  if (gameActive) {
    if (winnerTeam >= 0) {
      // Enhanced winner display
      display.setCursor(0, 0);
      display.setTextSize(1);
      display.println("    *** WINNER ***");
      display.println();

      // Team name large and centered
      display.setTextSize(2);
      String name = teams[winnerTeam].name;
      if (name.length() > 10) name = name.substring(0, 10);  // Truncate if needed
      int16_t x1, y1;
      uint16_t w, h;
      display.getTextBounds(name.c_str(), 0, 0, &x1, &y1, &w, &h);
      display.setCursor((SCREEN_WIDTH - w) / 2, 20);
      display.println(name);

      // Response time
      display.setTextSize(1);
      display.setCursor(0, 44);
      display.printf("    Response: %lu ms", winnerTime);

      // Reset instruction
      display.setCursor(0, 56);
      display.print(" Press RESET for next Q");

    } else {
      // Live scoreboard - show all teams with status
      display.setTextSize(1);
      display.printf("GAME ON     Teams:%d/%d", countOnlineTeams(), countConfiguredTeams());
      display.setCursor(0, 10);

      // Draw 2-column grid of configured teams
      int col = 0;
      int row = 0;
      for (int i = 0; i < MAX_TEAMS; i++) {
        if (teams[i].isConfigured) {
          int x = col * 64;
          int y = 10 + (row * 9);

          display.setCursor(x, y);
          // Team number and truncated name
          String shortName = teams[i].name.substring(0, 6);
          display.printf("%d.%s", i + 1, shortName.c_str());

          // Status indicator
          display.setCursor(x + 56, y);
          display.print(getTeamStatusChar(i));

          col++;
          if (col >= 2) {
            col = 0;
            row++;
          }
        }
      }

      // Status bar at bottom
      display.setCursor(0, 56);
      display.print(">>> WAITING FOR BUZZ <<<");
    }

  // --- GAME STOPPED MODE ---
  } else {
    int connectedCount = countOnlineTeams();

    // WiFi info header
    display.printf("SSID: %s\n", ap_ssid.c_str());
    display.printf("IP: %s\n", WiFi.softAPIP().toString().c_str());
    display.printf("Teams: %d/%d\n", connectedCount, MAX_TEAMS);
    display.println();

    if (connectedCount > 0) {
      // Cycle through connected teams
      unsigned long currentTime = millis();
      if (currentTime - lastDisplayUpdate >= DISPLAY_CYCLE_INTERVAL_MS) {
        lastDisplayUpdate = currentTime;

        // Find next connected team
        int startTeam = currentDisplayTeam;
        do {
          currentDisplayTeam = (currentDisplayTeam + 1) % MAX_TEAMS;
        } while (!teams[currentDisplayTeam].isConfigured || !teams[currentDisplayTeam].isOnline);

        // Prevent infinite loop if no teams connected
        if (currentDisplayTeam == startTeam && (!teams[currentDisplayTeam].isConfigured || !teams[currentDisplayTeam].isOnline)) {
          currentDisplayTeam = 0;
        }
      }

      // Display current team info
      if (teams[currentDisplayTeam].isConfigured && teams[currentDisplayTeam].isOnline) {
        display.setTextSize(2);
        display.printf("Team %d\n", currentDisplayTeam + 1);
        display.println(teams[currentDisplayTeam].name);
        display.setTextSize(1);
        if (teams[currentDisplayTeam].isMuted) {
          display.println("[MUTED]");
        }
      }
    } else {
      display.println("No teams connected");
      display.println("Configure teams via");
      display.println("web interface");
    }
  }

  display.display();
}
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

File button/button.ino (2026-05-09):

#include <esp_now.h>
#include <WiFi.h>
#include <esp_wifi.h>
#include <Wire.h>
#include <Adafruit_GFX.h>
#include <Adafruit_SSD1306.h>
#include "button-secret.h"

// Display configuration
#define SCREEN_WIDTH 128
#define SCREEN_HEIGHT 32
#define OLED_RESET -1
Adafruit_SSD1306 display(SCREEN_WIDTH, SCREEN_HEIGHT, &Wire, OLED_RESET);

// Pin definitions for ESP32-C6 (Breadboard Version)
#define I2C_SDA 6
#define I2C_SCL 7
#define BUTTON_PIN 15 // Button input pin
#define STATUS_LED_PIN 2 // Built-in LED for status (optional)
#define SPEAKER_PIN 8 // PWM pin for 3W speaker
#define BATTERY_PIN 1 // ADC pin for battery voltage monitoring (GPIO1/A0)

// Base station MAC address
uint8_t baseStationMAC[] = BASE_STATION_MAC;

bool ledState = false;
unsigned long lastPressTime = 0;
const unsigned long debounceDelay = 50;

// Declare the flag used in the Interrupt Service Routine (ISR)
volatile bool buttonPressed = false; 

// Global debug variables
unsigned long lastHeartbeatTime = 0;
bool heartbeatSuccess = false;
int messagesReceived = 0;

// Game state
enum ButtonState {
  WAITING, // Waiting for game to start
  READY, // Game active, ready to buzz
  WINNER, // This button buzzed first
  LOCKED_OUT // Another button buzzed first
};

ButtonState currentState = WAITING;
String teamName = ""; // Team name received from base station
uint16_t responseTimeMs = 0; // Response time in ms (received from base station for winner)

// Debug counters for OLED display
int buttonPressCount = 0;
int messagesSent = 0;

// Track state changes to prevent repeating sounds
ButtonState lastState = WAITING;

// Audio settings
bool audioMuted = false;

// Battery monitoring
float batteryVoltage = 0.0;
int batteryPercent = 0;
unsigned long lastBatteryRead = 0;
const unsigned long batteryReadInterval = 30000; // Read battery every 30 seconds

// Connection tracking
#define CONNECTION_TIMEOUT_MS 15000  // Consider disconnected after 15 seconds
#define LOW_BATTERY_THRESHOLD 15     // Show warning when battery < 15%
bool isConnected = false;
unsigned long lastBaseStationMsg = 0;

// Interrupt handler for button press
void IRAM_ATTR buttonISR() {
  buttonPressed = true;
}

// ESP-NOW callback for receiving data from base station
// Message format:
//   Byte 0: Status code (0=stopped, 1=winner, 2=locked, 3=ready)
//   Byte 1: Mute flag (0=unmuted, 1=muted)
//   Bytes 2-3: Response time in ms (uint16_t, little-endian)
//   Bytes 4-31: Team name (up to 27 chars + null terminator)
void onDataRecv(const esp_now_recv_info *recv_info, const uint8_t *incomingData, int len) {
  if (len < 1) return;

  // Track connection status
  lastBaseStationMsg = millis();
  isConnected = true;

  uint8_t response = incomingData[0];
  messagesReceived++; // Count messages received

  // Extract mute flag, response time, and team name if message is long enough
  if (len >= 4) {
    audioMuted = (incomingData[1] == 1);

    // Extract response time (uint16_t, little-endian)
    responseTimeMs = incomingData[2] | (incomingData[3] << 8);

    // Team name starts at byte 4
    teamName = String((char*)&incomingData[4]);
    teamName.trim(); // Remove any trailing whitespace
    Serial.printf("Received team name: '%s', muted: %s, responseTime: %dms\n",
                  teamName.c_str(), audioMuted ? "YES" : "NO", responseTimeMs);
  } else if (len > 2) {
    // Backwards compatibility with old message format (just mute + team name)
    audioMuted = (incomingData[1] == 1);
    teamName = String((char*)&incomingData[2]);
    teamName.trim();
    Serial.printf("Received team name (old format): '%s', muted: %s\n", teamName.c_str(), audioMuted ? "YES" : "NO");
  }
  
  // Debug: Print received message
  Serial.printf("Received ESP-NOW message: %d\n", response);
  
  switch (response) {
    case 0: // Game stopped
      currentState = WAITING;
      setStatusLED(false);
      updateDisplay();
      Serial.println("Game stopped");
      break;
      
    case 1: // Winner!
      currentState = WINNER;
      blinkStatusLED(5); // Blink 5 times to celebrate
      setStatusLED(true); // Keep LED on
      playWinnerSound(); // Victory fanfare
      updateDisplay();
      Serial.println("We won!");
      break;
      
    case 2: // Locked out (another team won)
      currentState = LOCKED_OUT;
      setStatusLED(false);
      // No automatic lockout sound - only play when button pressed while locked
      updateDisplay();
      Serial.println("Locked out");
      break;
      
    case 3: // Game active, ready to buzz
      // Only play ready sound if this is a new state change
      if (currentState != READY) {
        playReadySound(); // Quick ready beep only on state change
      }
      currentState = READY;
      setStatusLED(false);
      updateDisplay();
      Serial.println("Game active - ready!");
      break;
  }
}

// Updated callback signature for ESP32 Arduino Core 3.x
void onDataSent(const wifi_tx_info_t *tx_info, esp_now_send_status_t status) {
  heartbeatSuccess = (status == ESP_NOW_SEND_SUCCESS);
  Serial.print("Send Status: ");
  Serial.println(status == ESP_NOW_SEND_SUCCESS ? "Success" : "Fail");
}

// Draw battery icon in top-right corner
void drawBatteryIcon(int x, int y, int percent) {
  // Battery outline (12x6 pixels)
  display.drawRect(x, y, 10, 6, SSD1306_WHITE); // Main body
  display.drawRect(x + 10, y + 2, 2, 2, SSD1306_WHITE); // Terminal

  // Fill battery based on percentage
  if (percent > 75) {
    display.fillRect(x + 1, y + 1, 8, 4, SSD1306_WHITE); // Full
  } else if (percent > 50) {
    display.fillRect(x + 1, y + 1, 6, 4, SSD1306_WHITE); // 75%
  } else if (percent > 25) {
    display.fillRect(x + 1, y + 1, 4, 4, SSD1306_WHITE); // 50%
  } else if (percent > 10) {
    display.fillRect(x + 1, y + 1, 2, 4, SSD1306_WHITE); // 25%
  }
  // If <= 10%, show empty battery (outline only)

  // Show percentage text next to battery
  display.setCursor(x - 18, y);
  display.setTextSize(1);
  if (percent < 100) {
    display.print(" ");
  }
  display.print(percent);
  display.print("%");
}

// Helper: Draw connection indicator icon
void drawConnectionIcon(int x, int y, bool connected) {
  if (connected) {
    // Filled WiFi-like icon (3 arcs)
    display.fillCircle(x + 3, y + 5, 1, SSD1306_WHITE);  // Center dot
    display.drawLine(x + 1, y + 3, x + 5, y + 3, SSD1306_WHITE);  // Arc 1
    display.drawLine(x, y + 1, x + 6, y + 1, SSD1306_WHITE);      // Arc 2
  } else {
    // Outline only (disconnected)
    display.drawCircle(x + 3, y + 5, 1, SSD1306_WHITE);
    display.drawPixel(x + 2, y + 3, SSD1306_WHITE);
    display.drawPixel(x + 4, y + 3, SSD1306_WHITE);
    // X mark to show disconnected
    display.drawLine(x, y, x + 6, y + 6, SSD1306_WHITE);
    display.drawLine(x + 6, y, x, y + 6, SSD1306_WHITE);
  }
}
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

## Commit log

2025-10-29 Reworked all of base station...
    [base-station.ino]
2025-10-29 Added game logic and ESP32-NOW
2025-10-29 Working base and button communication! 🎉
2025-10-30 Added button press count for debugging
2025-12-11 Implement code quality improvements and documentation fixes
    Code improvements:
    - Refactor sendButtonResponses/sendTeamStatusUpdate to eliminate duplication
    - Add constants for magic numbers (timeouts, message sizes, status codes)
    - Add HTML escaping for team names to prevent XSS vulnerabilities
    - Add MAC address input validation with regex pattern in web form
    - Add battery reading averaging (10 samples) for more stable readings
    - Extend ESP-NOW protocol to include response time (bytes 2-3)
    - Display response time on button OLED when winner
    Documentation fixes:
    - Create MIT LICENSE file (was referenced but missing)
    - Fix README.md repository structure to match actual files
    - Update secret fi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
    [base-station.ino, button.ino]
2025-12-11 Add modern teacher-friendly UI and button auto-discovery
    UI Improvements:
    - Complete redesign with dark theme and large touch-friendly buttons
    - Separate Game page (main controls) from Settings page (configuration)
    - Auto-refresh every 3 seconds for live status updates
    - Hide technical details (MAC addresses) from main view
    - Color-coded status indicators (green=online, orange=offline)
    - Large gradient buttons for game control (Start, Stop, Reset)
    - Winner display with team name and response time
    - Simplified team list showing only configured teams
    Auto-Discovery Feature:
    - Buttons are automatically detected when powered on
    - Unknown MACs are added to "pending" list (max 5)
    - Settings page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
    [base-station.ino]
2025-12-23 major structure overhaul
    [base-station-handheld-back.scad, base-station-handheld-back.stl, base-station-handheld-front.scad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]
2026-05-09 updated designs
    [button-housing - top.stl, button-housing.scad]
